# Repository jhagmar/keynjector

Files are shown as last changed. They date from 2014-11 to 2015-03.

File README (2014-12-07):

ABOUT THE PROJECT

There are several bad solutions to managing passwords securely, e.g.,

1) Having the same (easy to guess) password for every account
2) Keeping your passwords on a Post-It under your keyboard
3) Using a password manager on your computer

You might be surprised that item 3 made the list, but password managers keep all passwords in a file encrypted with a master password. When the user retrieves a password, all other passwords are decrypted and exposed in RAM, in an environment with dozens of other, potentially malicious, processes with internet access. Password managing software often use secure memory to increase security. However, a keylogger can be used to record the master password, and then we are back at the original problem.

The keynjector project tries to raise the bar by providing the password file decryption in a dedicated device, connected to the host with a USB cable. The password file, encrypted with OpenPGP symmetric encryption, is provided on a microSD card that the user inserts into the device. When the user requests a password, the device emulates a USB keyboard, and types the password on the host computer.

This solution offers a more secure solution compared to a traditional password manager:
1) There are no other processes running on the device that could potentially steal the information.
2) The USB keyboard interface is one-directional. There is no possibility for the host to inject code into the keynjector device.
3) The master password file can be easily removed and destroyed, e.g., by burning the microSD card, if needed.
4) The device can be used on any computer that recognizes a USB keyboard, without any loss of security.

The keynjector project consists of several sub-projects for the PCB layout, the firmware, the case for the device, etc. See below for a brief overview of the project directory structure.

GENERAL INFORMATION

Unless otherwise stated, all files in the keynjector project are Copyright Jonas Hagmar 2014, and licensed under GPL v2. A copy of the GPL v2 can be found in LICENSE.

Please refer to the AUTHORS file for contact information. 

DIRECTORY STRUCTURE

A brief overview of the directory structure of the project:

cad - CAD drawings

cad/case - OpenSCAD drawing of the case, suitable for 3D printing.

docs - documents

docs/datasheets - datasheets of components listed in the bill of materials (BOM)

hw - hardware designs

hw/bom - BOM for the hardware designs

hw/keynjector - KiCad project for the keynjector PCB

hw/zifbrkout - KiCad project for a breakout board which is helpful for testing the LCD connector on the keynjector board

misc - miscellaneous

misc/fonts - fonts used in the keynjector software

sw - software

sw/keynjector - Atmel Studio ASF project for the keynjector firmware

sw/keynjector_ui - Visual Studio 2010 project for desktop development of the keynjector UI, for faster iterations than trying out the code directly on the keynjector board

THIRD PARTY LICENSES

The project uses the following third party software:

Atmel ASF

/* Copyright (c) 2009-2014 Atmel Corporation. All rights reserved.
 *
 * \asf_license_start
 *
 * \page License
 *
 * Redistribution and use in source and binary forms, with or without
 * modification, are permitted provided that the following conditions are met:
 *
 * 1. Redistributions of source code must retain the above copyright notice,
 *    this list of conditions and the following disclaimer.
 *
 * 2. Redistributions in binary form must reproduce the above copyright notice,
 *    this list of conditions and the following disclaimer in the documentation
 *    and/or other materials provided with the distribution.
 *
 * 3. The name of Atmel may not be used to endorse or promote products derived
 *    from this software without specific prior written permission.
 *
 * 4. This software may only be redistributed and used in connection with an
 *    Atmel microcontroller product.
 *
 * THIS SOFTWARE IS PROVIDED BY ATMEL "AS IS" AND ANY EXPRESS OR IMPLIED
 * WARRANTIES, INCLUDING, BUT NOT LIMITED TO, THE IMPLIED WARRANTIES OF
 * MERCHANTABILITY, FITNESS FOR A PARTICULAR PURPOSE AND NON-INFRINGEMENT ARE
 * EXPRESSLY AND SPECIFICALLY DISCLAIMED. IN NO EVENT SHALL ATMEL BE LIABLE FOR
 * ANY DIRECT, INDIRECT, INCIDENTAL, SPECIAL, EXEMPLARY, OR CONSEQUENTIAL
 * DAMAGES (INCLUDING, BUT NOT LIMITED TO, PROCUREMENT OF SUBSTITUTE GOODS
 * OR SERVICES; LOSS OF USE, DATA, OR PROFITS; OR BUSINESS INTERRUPTION)
 * HOWEVER CAUSED AND ON ANY THEORY OF LIABILITY, WHETHER IN CONTRACT,
 * STRICT LIABILITY, OR TORT (INCLUDING NEGLIGENCE OR OTHERWISE) ARISING IN
 * ANY WAY OUT OF THE USE OF THIS SOFTWARE, EVEN IF ADVISED OF THE
 * POSSIBILITY OF SUCH DAMAGE.
 *
 * \asf_license_stop
 *
 */

CMSIS

* -------------------------------------------------------------------
* Copyright (C) 2011 ARM Limited. All rights reserved.  
* 
* Date:        11 October 2011  
* Revision:    V3.00 
*  
* Project:     Cortex Microcontroller Software Interface Standard (CMSIS)
* Title:       Release Note for CMSIS
*
* -------------------------------------------------------------------

NOTE - Open the index.html file to access CMSIS documentation

The Cortex Microcontroller Software Interface Standard (CMSIS) provides a single standard across all 
Cortex-Mx processor series vendors. It enables code re-use and code sharing across software projects 
and reduces time-to-market for new embedded applications.

CMSIS is released under the terms of the end user license agreement ("CMSIS END USER LICENCE AGREEMENT.pdf").
Any user of the software package is bound to the terms and conditions of the end user license agreement.

FatFS

 FatFs module is an open source software to implement FAT file system to
 small embedded systems. This is a free software and is opened for education,
 research and commercial developments under license policy of following trems.

  Copyright (C) 2011, ChaN, all right reserved.

 * The FatFs module is a free software and there is NO WARRANTY.
 * No restriction on use. You can use, modify and redistribute it for
   personal, non-profit or commercial product UNDER YOUR RESPONSIBILITY.
 * Redistributions of source code must retain the above copyright notice.

miniz

miniz is public domain and has the following license:

/*
  This is free and unencumbered software released into the public domain.

  Anyone is free to copy, modify, publish, use, compile, sell, or
  distribute this software, either in source code form or as a compiled
  binary, for any purpose, commercial or non-commercial, and by any
  means.

  In jurisdictions that recognize copyright laws, the author or authors
  of this software dedicate any and all copyright interest in the
  software to the public domain. We make this dedication for the benefit
  of the public at large and to the detriment of our heirs and
  successors. We intend this dedication to be an overt act of
  relinquishment in perpetuity of all present and future rights to this
  software under copyright law.

  THE SOFTWARE IS PROVIDED "AS IS", WITHOUT WARRANTY OF ANY KIND,
  EXPRESS OR IMPLIED, INCLUDING BUT NOT LIMITED TO THE WARRANTIES OF
  MERCHANTABILITY, FITNESS FOR A PARTICULAR PURPOSE AND NONINFRINGEMENT.
  IN NO EVENT SHALL THE AUTHORS BE LIABLE FOR ANY CLAIM, DAMAGES OR
  OTHER LIABILITY, WHETHER IN AN ACTION OF CONTRACT, TORT OR OTHERWISE,
  ARISING FROM, OUT OF OR IN CONNECTION WITH THE SOFTWARE OR THE USE OR
  OTHER DEALINGS IN THE SOFTWARE.

  For more information, please refer to <http://unlicense.org/>
*/

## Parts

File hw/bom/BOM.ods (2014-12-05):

# boards | 3
Unit | Part number | Link | Footprint | Qty/board | Fixed qty | Qty | Total qty
Processor | ATSAM4S8BA-ANR | http://www.digikey.se/product-detail/en/ATSAM4S8BA-ANR/ATSAM4S8BA-ANRCT-ND/4557105 | Yes (LQFP64) | 1 |  | 3 | 3
40 pin ZIF/FFC | FH12A-40S-0.5SH(55) | http://www.digikey.se/product-detail/en/FH12A-40S-0.5SH(55)/HFK140CT-ND/1110402 | Yes | 1 |  | 3 | 3
Voltage regulator | SPX3819M5-L/TR | http://www.digikey.se/product-detail/en/SPX3819M5-L%2FTR/1016-1871-1-ND/3586588 | Yes (SOT-23-5) | 1 |  | 3 | 3
Display | NHD-2.4-240320SF-CTXL#-FTN1 | http://www.digikey.se/product-detail/en/NHD-2.4-240320SF-CTXL%23-FTN1/NHD-2.4-240320SF-CTXL%23-FTN1-ND/4429440 | N/A | 1 |  | 3 | 3
10uF tantalum Capacitor, 16V 10% | TR3A106K016C1700 | http://www.digikey.se/product-detail/en/TR3A106K016C1700/718-1301-1-ND/1663023 | Yes (1206_10uF) | 1 |  | 3 | 3
Touch screen controller | ADS7843E | http://www.digikey.se/product-detail/en/ADS7843E/ADS7843E-ND/299533 | Yes (SSOP-16) | 1 |  | 3 | 3
Micro SD connector | 492250821 | http://www.digikey.se/product-detail/en/0492250821/WM3295CT-ND/2405740 | 492250821 | 1 |  | 3 | 3
Micro USB B connector | 10118192-0001LF | http://www.digikey.se/product-detail/en/10118192-0001LF/609-4613-1-ND/2785378 | Yes (10118192) | 1 |  | 3 | 3
100nF ceramic capacitor, 16V 10% | CL21B104KOANNNC | http://www.digikey.se/product-detail/en/CL21B104KOANNNC/1276-2448-1-ND/3890534 | Yes (0805) | 14 |  | 42 | 42
ESD protection diode | PRTR5V0U2X,215 | http://www.digikey.se/product-detail/en/PRTR5V0U2X,215/568-4140-1-ND/1589981 | Yes (SOT143B) | 1 |  | 3 | 3
15pF ceramic capacitor, 50V 5% | CL21C150JBANNNC | http://www.digikey.se/product-detail/en/CL21C150JBANNNC/1276-1163-1-ND/3889249 | Yes (0805) | 2 |  | 6 | 6
12 MHz crystal | 7A-12.000MAAJ-T | http://www.digikey.se/product-detail/en/7A-12.000MAAJ-T/887-1081-1-ND/2118958 | Yes 7A-12.000MAAJ-T) | 1 |  | 3 | 3
Atmel ICE debugger | ATATMEL-ICE | http://www.digikey.se/product-detail/en/ATATMEL-ICE/ATATMEL-ICE-ND/4753379 | N/A |  | 1 | 0 | 1
Solder 0.4mm leaded | 386844 | http://www.digikey.se/product-detail/en/386844/82-117-ND/2498915 | N/A |  | 1 | 0 | 1
Cortex debug header | M50-3600542 | http://www.digikey.se/product-detail/en/M50-3600542/952-1389-ND/2264370 | Yes (M50-3600542) | 1 |  | 3 | 3
Tactile switch | EVQ-P7L01P | http://www.digikey.se/product-detail/en/EVQ-P7L01P/P16769CT-ND/4429462 | Yes (EVQP7L01P) | 1 |  | 3 | 3
100K thick film resistor. 1/8W 1% | RMCF0805FT100K | http://www.digikey.se/product-detail/en/RMCF0805FT100K/RMCF0805FT100KCT-ND/1942491 | Yes (0805) | 0 |  | 0 | 0
36k thick film resistor, 1/8 W 1% | RMCF0805FT36K0 | http://www.digikey.se/product-detail/en/RMCF0805FT36K0/RMCF0805FT36K0CT-ND/2418379 | Yes (0805) | 1 |  | 3 | 3
56k thick film resistor, 1/8 W 1% | RC0805FR-0756KL | http://www.digikey.se/product-detail/en/RC0805FR-0756KL/311-56.0KCRCT-ND/730980 | Yes (0805) | 1 |  | 3 | 3
2.2uF tantalum capacitor, 10% 6Ohm | T491A225K016AT | http://www.digikey.se/product-detail/en/T491A225K016AT/399-3691-1-ND/819016 | Yes (1206_2.2uF) | 1 |  | 3 | 3
10uF ceramic capacitor, 16V 10% | CL21A106KOQNNNE | http://www.digikey.se/product-detail/en/CL21A106KOQNNNE/1276-1096-1-ND/3889182 | Yes (0805) | 4 |  | 12 | 12
39R thick film resistor, 1/8 W 1% | RC0805FR-0739RL | http://www.digikey.se/product-detail/en/RC0805FR-0739RL/311-39.0CRCT-ND/730845 | Yes (0805) | 3 |  | 9 | 9
10K thick film resistor. 1/8W 1% | RMCF0805FT10K0 | http://www.digikey.se/product-detail/en/RMCF0805FT10K0/RMCF0805FT10K0CT-ND/1942435 | Yes (0805) | 2 |  | 6 | 6
zifbrkout
FFC cable | 687640050002 | http://www.digikey.se/product-detail/en/687640050002/732-3571-ND/2811293 |  | 1
LED | LY R976-PS-36 | http://www.digikey.se/product-detail/en/LY%20R976-PS-36/475-2560-1-ND/1802687 |  | 40
330R resistor | RMCF0805FT330R | http://www.digikey.se/product-detail/en/RMCF0805FT330R/RMCF0805FT330RCT-ND/1942351 |  | 40
Vertical ZIF connector | 501951-4000 | http://www.digikey.se/product-detail/en/501951-4000/WM2075CT-ND/1952421 |  | 1
Accessories
10x loupe | 26034 | http://www.digikey.se/product-detail/en/26034/243-1021-ND/600975 |  |  | 1 | 0 | 1
loupe headgear | 26225 | http://www.digikey.se/product-detail/en/26225/243-1124-ND/2756906 |  |  | 1 | 0 | 1
Solder wick | OS-B-5AS | http://www.digikey.se/product-detail/en/OS-B-5AS/EB1102-ND/350557 |  |  | 1 | 0 | 1
Flux paste | SMD291 | http://www.digikey.se/product-detail/en/SMD291/SMD291-ND/355201 |  |  | 1 | 0 | 1
1/32" solder tip | LTH | http://www.digikey.se/product-detail/en/LTH/LTH-ND/267992 |  |  | 1 | 0 | 1
0.4 mm solder tip | LT1SLX | http://www.digikey.se/product-detail/en/LT1SLX/LT1SLX-ND/588691 |  |  | 1 | 0 | 1
Flux pen/liquid flux |  | http://www.electrokit.com/flussmedel-penna-10ml.49540 |  |  | 1 | 0 | 1
 |  | http://www.electrokit.com/flussmedel-penna-noclean-10ml.50507 |  |  |  | 0 | 0
Solder practice kit | SMDPST100 | http://www.digikey.se/product-search/en?FV=fff40026,fff80267,fffc013b&chp=0 |  |  | 1 | 0 | 1
Removal kit | SMD1 | http://www.digikey.se/product-detail/en/SMD1/SMD1-ND/304148 |  |  | 1 | 0 | 1
Vacuum tool | HVPB6 | http://www.digikey.se/product-detail/en/HVPB6/HVPB6-ND/1164270 |  |  | 1 | 0 | 1
Tweezers | 18072EZ | http://www.digikey.se/product-detail/en/18072EZ/243-1055-ND/1657714 |  |  | 1 | 0 | 1
Dry tip cleaner |  | http://www.electrokit.com/lodspetsrengorare-metallull.50289 |  |  | 1 | 0 | 1
Tip tinner | SMDTCLF | http://www.digikey.se/product-detail/en/SMDTCLF/SMDTCLF-ND/2177048 |  |  | 1 | 0 | 1

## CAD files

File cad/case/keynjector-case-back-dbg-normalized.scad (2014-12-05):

/*
* Copyright 2014 Jonas Hagmar
*
* This file is part of keynjector.
*
* keynjector is free software: you can redistribute it and/or modify
* it under the terms of the GNU General Public License as published by
* the Free Software Foundation, either version 2 of the License, or
* (at your option) any later version.
*
* keynjector is distributed in the hope that it will be useful,
* but WITHOUT ANY WARRANTY; without even the implied warranty of
* MERCHANTABILITY or FITNESS FOR A PARTICULAR PURPOSE.  See the
* GNU General Public License for more details.
*
* You should have received a copy of the GNU General Public License
* along with keynjector.  If not, see <http://www.gnu.org/licenses/>.
*/

use <keynjector-case.scad>;

/***** Renders *****/

$fn=100;

case_back_dbg_normalized();

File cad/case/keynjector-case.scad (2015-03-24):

/*
* Copyright 2014 Jonas Hagmar
*
* This file is part of keynjector.
*
* keynjector is free software: you can redistribute it and/or modify
* it under the terms of the GNU General Public License as published by
* the Free Software Foundation, either version 2 of the License, or
* (at your option) any later version.
*
* keynjector is distributed in the hope that it will be useful,
* but WITHOUT ANY WARRANTY; without even the implied warranty of
* MERCHANTABILITY or FITNESS FOR A PARTICULAR PURPOSE.  See the
* GNU General Public License for more details.
*
* You should have received a copy of the GNU General Public License
* along with keynjector.  If not, see <http://www.gnu.org/licenses/>.
*/

/***** Parameters *****/

tol = 0.1; // tolerance
eps = 0.01;
wall_thickness = 1; // thickness of case wall
front_thickness = 0.5; // thickness of front wall
pcb_width = 42.94 + tol;
pcb_drawing_height = 35.96;
pcb_height = 36.2 + tol;
pcb_depth = 1.76 + tol;
component_depth = 2.7 + tol; // largest component is USB connector
screen_width = 42.72 + tol;
screen_height = 60.26 + tol;
screen_back_film_thickness = 0.1;
screen_depth = 3.6 + screen_back_film_thickness + tol;
screen_top = 2.9; // distance from top to viewport
holder_height = 10; // height of screen holder
holder_width = 8;
usb_a = 4.75;
usb_b = 7.86;
usb_c = 2.8;
usb_zoffset = -0.1;
btn_width = 2;
btn_height = 10;
btn_y_offset = -7.24;
btn_base_height = 12;
btn_base_depth = 0.95;
btn_ratio = 0.95; // ration of button size to hole
btn_protrude = 0.5;
sd_y_offset = -18.3;
sd_height = 12;
sd_depth = 2;
nut_depth = 1.6; // max depth of DIN 934 M2 nut
nut_diameter = 4; // diameter of DIN 934 M2 nut
nut_clearance = 0.2;
screw_head_diameter = 3.8; // DIN 965 M2
screw_body_diameter = 2; // DIN 965 M2
screw_depth = 5;
dbg_y_offset = -26; // offset for debug header window
dbg_holder_dent_size = 2;
dbg_x_offset = -8; 
pcb_real_height_offset = (pcb_height - pcb_drawing_height)/2;
usb_coord = [[usb_a/2,0], [usb_b/2, (usb_b - usb_a)/2],
	[usb_b/2, usb_c], [-usb_b/2, usb_c],
	[-usb_b/2, (usb_b - usb_a)/2], [-usb_a/2, 0]];
case_width = pcb_width + 2*wall_thickness;
case_height = screen_height + 2*wall_thickness;
case_depth = pcb_depth + component_depth + screen_depth + wall_thickness
	+ front_thickness;
fillet_radius = 1;
screen_x2 = [screen_width/2, case_height/2 - wall_thickness,
	case_depth/2 - front_thickness];
screen_x1 = screen_x2 - [screen_width, screen_height, screen_depth];
pcb_x2 = [pcb_width/2, case_height/2 - wall_thickness,
	-case_depth/2 + pcb_depth + wall_thickness];
pcb_x1 = pcb_x2 - [pcb_width, pcb_height, pcb_depth];
comp_x2 = pcb_x2 + [0,0,component_depth]; // component layer
comp_x1 = pcb_x1 + [0,0,pcb_depth];
cable_x2 = [case_width/2 - wall_thickness, pcb_x1[1] + eps,
	case_depth/2 - front_thickness];
cable_x1 = [-case_width/2 + wall_thickness, 
	-case_height/2 + wall_thickness, -case_depth/2 + wall_thickness]; 
viewport_fillet_radius = front_thickness;
viewport_width = 36.72;
viewport_height = 48.96;
viewport_x2 = [viewport_width/2 + viewport_fillet_radius,
	case_height/2 - wall_thickness - screen_top + viewport_fillet_radius, 
	case_depth/2 + wall_thickness];
viewport_x1 = [viewport_x2[0] - viewport_width - 2*viewport_fillet_radius,
	viewport_x2[1] - viewport_height - 2*viewport_fillet_radius,
	viewport_x2[2] - case_depth];
holder1_x1 = [-case_width/2 + wall_thickness,
	pcb_x1[1] - holder_height, -case_depth/2 + wall_thickness];
holder1_x2 = [holder1_x1[0] + holder_width, holder1_x1[1] + holder_height,
	case_depth/2 - front_thickness - screen_depth];
holder2_x1 = holder1_x1 
	+ [case_width - 2*wall_thickness - holder_width,0,0];
holder2_x2 = holder1_x2 
	+ [case_width - 2*wall_thickness - holder_width,0,0];
dbg_x2 = [case_width/2 - wall_thickness + eps,
	case_height/2 - wall_thickness + dbg_y_offset,
	case_depth/2 - front_thickness - eps];
dbg_x1 = [dbg_x2[0] + dbg_x_offset,
	pcb_x1[1] - dbg_holder_dent_size, -case_depth/2 - eps];
sup_size = 1; // size of display support
sup1_x1 = [pcb_x1[0], pcb_x2[1] - sup_size, pcb_x1[2]-eps];
sup1_x2 = [sup1_x1[0]+sup_size, sup1_x1[1]+sup_size, 
	sup1_x1[2]+pcb_depth+component_depth+eps];
sup2_x1 = sup1_x1 + [pcb_width - sup_size, 0, 0];
sup2_x2 = sup1_x2 + [pcb_width - sup_size, 0, 0];


/***** Renders *****/

//$fn=20;

case_back();
//case_back_normalized();

//case_back_dbg();
//case_back_dbg_normalized();

holder();
//holder_normalized();

case_front();
//case_front_normalized();

btn();
//btn_normalized();

/***** Modules *****/

module translated_sphere(r, x) {
	translate(x)
		sphere(r);
}

// construct a rounded cube by taking the hull of
// spheres in the corners
module rounded_cube(w, h, d, r) {
	hull() {
		translated_sphere(r, [w/2 - r, h/2 - r, 
			d/2 - r]);
		translated_sphere(r, [-w/2 + r, h/2 - r, 
			d/2 - r]);
		translated_sphere(r, [w/2 - r, -h/2 + r, 
			d/2 - r]);
		translated_sphere(r, [-w/2 + r, -h/2 + r, 
			d/2 - r]);
		translated_sphere(r, [w/2 - r, h/2 - r, 
			-d/2 + r]);
		translated_sphere(r, [-w/2 + r, h/2 - r, 
			-d/2 + r]);
		translated_sphere(r, [w/2 - r, -h/2 + r, 
			-d/2 + r]);
		translated_sphere(r, [-w/2 + r, -h/2 + r, 
			-d/2 + r]);	
	}
}

// convenience module to draw cube at specified coordinates
module box(x1, x2) {
	translate(x1)
			cube(x2 - x1);
}

// the solid body of the case
module case_body() {
	rounded_cube(case_width, case_height, case_depth, fillet_radius);
}

// viewport cut-out
module viewport_cut_out() {
	box(viewport_x1, viewport_x2);
}

// viewport fillet
module viewport_fillet() {
	union() {
		hull() {
			translated_sphere(viewport_fillet_radius,
				[viewport_x1[0], viewport_x1[1], 
					case_depth/2-viewport_fillet_radius]);
			translated_sphere(viewport_fillet_radius,
				[viewport_x1[0], viewport_x2[1], 
					case_depth/2-viewport_fillet_radius]);
		}
		hull() {
			translated_sphere(viewport_fillet_radius,
				[viewport_x1[0], viewport_x1[1], 
					case_depth/2-viewport_fillet_radius]);
			translated_sphere(viewport_fillet_radius,
				[viewport_x2[0], viewport_x1[1], 
					case_depth/2-viewport_fillet_radius]);
		}
		hull() {
			translated_sphere(viewport_fillet_radius,
				[viewport_x2[0], viewport_x2[1], 
					case_depth/2-viewport_fillet_radius]);
			translated_sphere(viewport_fillet_radius,
				[viewport_x1[0], viewport_x2[1], 
					case_depth/2-viewport_fillet_radius]);
		}
		hull() {
			translated_sphere(viewport_fillet_radius,
				[viewport_x2[0], viewport_x2[1], 
					case_depth/2-viewport_fillet_radius]);
			translated_sphere(viewport_fillet_radius,
				[viewport_x2[0], viewport_x1[1], 
					case_depth/2-viewport_fillet_radius]);
		}
	}
}

// lcd
module screen() {
	box(screen_x1, screen_x2);
}

// pcb with components
module pcb() {
	box(pcb_x1, pcb_x2 + [0,0,eps]);
}

module components() {
	box(comp_x1, comp_x2 + [0,0,eps]);
}

// empty space for cable
module cable_hole() {
	box(cable_x1, cable_x2);
}

// hole for micro usb B plug
module usb_hole() {
	translate([0, case_height/2, 
		-case_depth/2 + wall_thickness + pcb_depth + usb_zoffset])
	rotate(90, [1,0,0])
	linear_extrude(wall_thickness + eps)
	polygon(usb_coord);
}

// hole for user button
module btn_hole() {
	translate([case_width/2 + eps,
		case_height/2 - wall_thickness + btn_y_offset 
		- pcb_real_height_offset,
		- case_depth/2 + wall_thickness + pcb_depth + btn_width/2])
	rotate(-90, [0,0,1])
	rotate(90, [1,0,0])
	linear_extrude(wall_thickness + 2*eps) {
		hull() {
			translate([-btn_height/2 + btn_width/2,0,0])
				circle(btn_width/2);
			translate([btn_height/2 - btn_width/2,0,0])
				circle(btn_width/2);
		}
	}
}

// user button translated to have center at 0
module btn_normalized() {
	union() {
		linear_extrude(btn_base_depth)
		translate([-btn_base_height/2, -btn_width/2,0])
		square([btn_base_height, btn_width]);
		color([1,0,0])
		translate([0,0,btn_base_depth - eps])	
		linear_extrude(wall_thickness + btn_protrude + eps) {
			hull() {
				translate([btn_ratio * (-btn_height/2 + btn_width/2),0,0])
					circle(btn_ratio * btn_width/2);
				translate([btn_ratio *  (btn_height/2 - btn_width/2),0,0])
					circle(btn_ratio * btn_width/2);
			}
		}
	}
}

// user button
module btn() {
	translate([case_width/2,
		case_height/2 - wall_thickness + btn_y_offset 
		- pcb_real_height_offset,
		- case_depth/2 + wall_thickness + pcb_depth + btn_width/2])
	rotate(90, [0,0,1])
	rotate(90, [1,0,0])
	translate([0,0,-(btn_base_depth + wall_thickness)])
	btn_normalized();
}

// micro sd card slot
module sd_hole() {
	translate([-case_width/2 - eps,
		case_height/2 - wall_thickness + sd_y_offset 
		- pcb_real_height_offset,
		- case_depth/2 + wall_thickness + pcb_depth])
	rotate(90, [0,0,1])
	rotate(90, [1,0,0])
	linear_extrude(wall_thickness + 2*eps)
	translate([-sd_height/2, 0, 0])
	square([sd_height, sd_depth]);

}

// screen holders
module holder() {

	difference() {
		box(holder1_x1, holder1_x2);
		screws();
		nuts();
	}
	
	difference() {
		box(holder2_x1, holder2_x2);
		screws();
		nuts();
	}
	
}
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

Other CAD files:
cad/case/keynjector-case-back-normalized.scad
cad/case/keynjector-case-front-normalized.scad
cad/case/keynjector-holder-and-btn-normalized.scad

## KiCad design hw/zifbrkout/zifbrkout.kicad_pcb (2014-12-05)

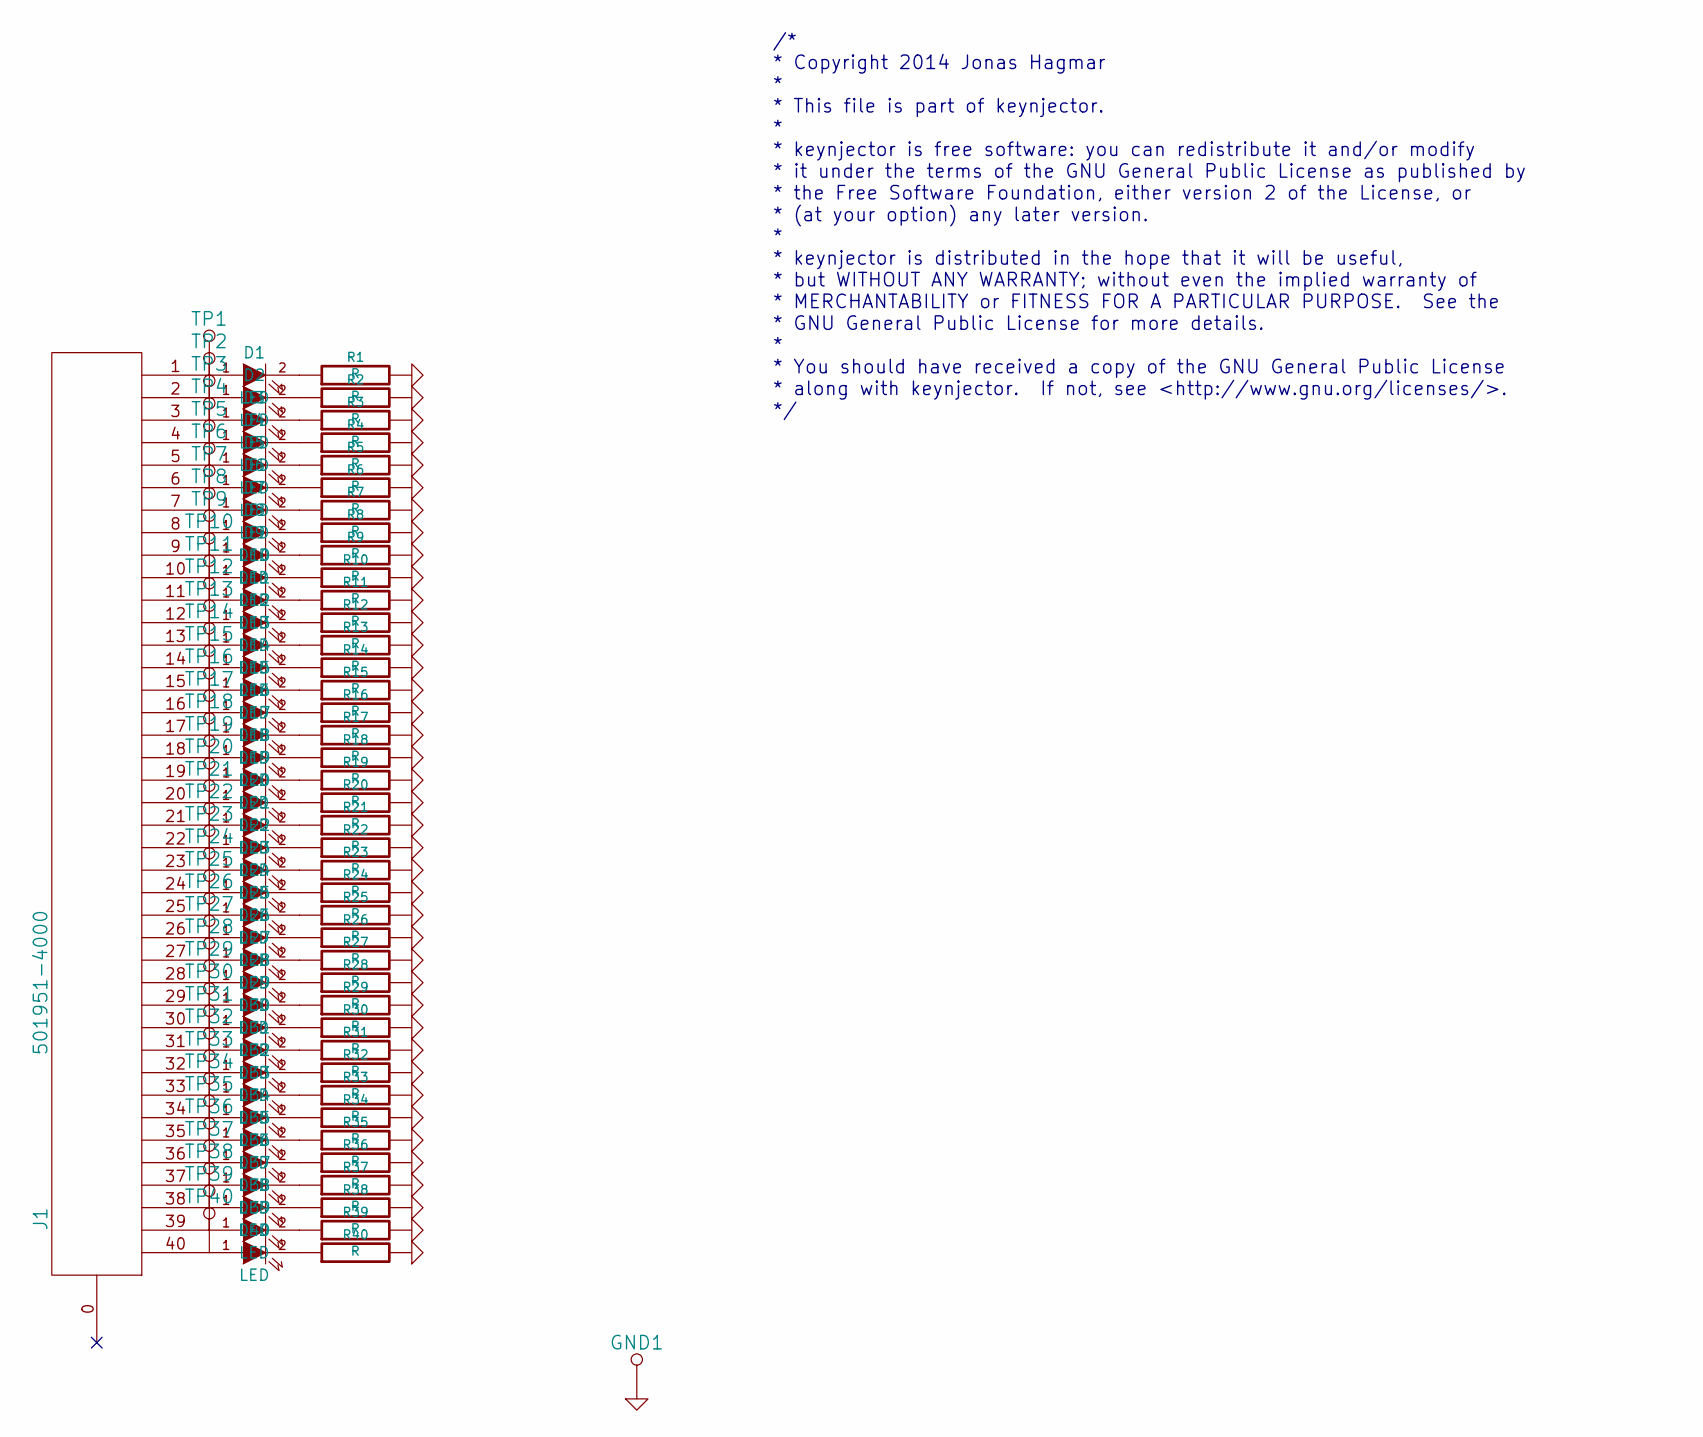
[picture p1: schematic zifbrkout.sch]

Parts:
D1, D2, D3, D4, D5, D6, D7, D8, D9, D10, D11, D12, D13, D14, D15, D16, D17, D18, D19, D20, D21, D22, D23, D24, D25, D26, D27, D28, D29, D30, D31, D32, D33, D34, D35, D36, D37, D38, D39, D40: LED
GND1: EXTGND
J1: 501951-4000
R1, R2, R3, R4, R5, R6, R7, R8, R9, R10, R11, R12, R13, R14, R15, R16, R17, R18, R19, R20, R21, R22, R23, R24, R25, R26, R27, R28, R29, R30, R31, R32, R33, R34, R35, R36, R37, R38, R39, R40: R
TP1, TP2, TP3, TP4, TP5, TP6, TP7, TP8, TP9, TP10, TP11, TP12, TP13, TP14, TP15, TP16, TP17, TP18, TP19, TP20, TP21, TP22, TP23, TP24, TP25, TP26, TP27, TP28, TP29, TP30, TP31, TP32, TP33, TP34, TP35, TP36, TP37, TP38, TP39, TP40: TP

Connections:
GND: GND1.1, R1.2, R2.2, R3.2, R4.2, R5.2, R6.2, R7.2, R8.2, R9.2, R10.2, R11.2, R12.2, R13.2, R14.2, R15.2, R16.2, R17.2, R18.2, R19.2, R20.2, R21.2, R22.2, R23.2, R24.2, R25.2, R26.2, R27.2, R28.2, R29.2, R30.2, R31.2, R32.2, R33.2, R34.2, R35.2, R36.2, R37.2, R38.2, R39.2, R40.2
unnamed: D26.2 (K), R26.1
unnamed: D31.2 (K), R31.1
unnamed: D30.2 (K), R30.1
unnamed: D29.2 (K), R29.1
unnamed: D28.2 (K), R28.1
unnamed: D27.2 (K), R27.1
unnamed: D25.2 (K), R25.1
unnamed: D24.2 (K), R24.1
unnamed: D23.2 (K), R23.1
unnamed: D22.2 (K), R22.1
unnamed: D40.2 (K), R40.1
unnamed: D39.2 (K), R39.1
unnamed: D38.2 (K), R38.1
unnamed: D37.2 (K), R37.1
unnamed: D36.2 (K), R36.1
unnamed: D35.2 (K), R35.1
unnamed: D34.2 (K), R34.1
unnamed: D33.2 (K), R33.1
unnamed: D32.2 (K), R32.1
unnamed: D11.1 (A), J1.11, TP11.1
unnamed: D24.1 (A), J1.24, TP24.1
unnamed: D14.1 (A), J1.14, TP14.1
unnamed: D33.1 (A), J1.33, TP33.1
unnamed: D23.1 (A), J1.23, TP23.1
unnamed: D13.1 (A), J1.13, TP13.1
unnamed: D32.1 (A), J1.32, TP32.1
unnamed: D22.1 (A), J1.22, TP22.1
unnamed: D12.1 (A), J1.12, TP12.1
unnamed: D31.1 (A), J1.31, TP31.1
unnamed: D21.1 (A), J1.21, TP21.1
unnamed: D34.1 (A), J1.34, TP34.1
unnamed: D40.1 (A), J1.40, TP40.1
unnamed: D30.1 (A), J1.30, TP30.1
unnamed: D20.1 (A), J1.20, TP20.1
unnamed: D10.1 (A), J1.10, TP10.1
unnamed: D9.1 (A), J1.9, TP9.1
unnamed: D8.1 (A), J1.8, TP8.1
unnamed: D7.1 (A), J1.7, TP7.1
unnamed: D6.1 (A), J1.6, TP6.1
unnamed: D5.1 (A), J1.5, TP5.1
unnamed: D18.1 (A), J1.18, TP18.1
unnamed: D39.1 (A), J1.39, TP39.1
unnamed: D29.1 (A), J1.29, TP29.1
unnamed: D19.1 (A), J1.19, TP19.1
unnamed: D38.1 (A), J1.38, TP38.1
unnamed: D28.1 (A), J1.28, TP28.1
unnamed: D4.1 (A), J1.4, TP4.1
unnamed: D37.1 (A), J1.37, TP37.1
unnamed: D27.1 (A), J1.27, TP27.1
unnamed: D17.1 (A), J1.17, TP17.1
unnamed: D36.1 (A), J1.36, TP36.1
unnamed: D26.1 (A), J1.26, TP26.1
unnamed: D16.1 (A), J1.16, TP16.1
unnamed: D35.1 (A), J1.35, TP35.1
unnamed: D25.1 (A), J1.25, TP25.1
unnamed: D15.1 (A), J1.15, TP15.1
unnamed: D3.1 (A), J1.3, TP3.1
unnamed: D2.1 (A), J1.2, TP2.1
unnamed: D1.1 (A), J1.1, TP1.1
unnamed: D21.2 (K), R21.1
unnamed: D8.2 (K), R8.1
unnamed: D7.2 (K), R7.1
unnamed: D6.2 (K), R6.1
unnamed: D5.2 (K), R5.1
unnamed: D4.2 (K), R4.1
unnamed: D9.2 (K), R9.1
unnamed: D3.2 (K), R3.1
unnamed: D2.2 (K), R2.1
unnamed: D14.2 (K), R14.1
unnamed: D18.2 (K), R18.1
unnamed: D17.2 (K), R17.1
unnamed: D16.2 (K), R16.1
unnamed: D15.2 (K), R15.1
unnamed: D13.2 (K), R13.1
unnamed: D12.2 (K), R12.1
unnamed: D11.2 (K), R11.1
unnamed: D10.2 (K), R10.1
unnamed: D1.2 (K), R1.1
unnamed: D19.2 (K), R19.1
unnamed: D20.2 (K), R20.1

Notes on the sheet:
/* * Copyright 2014 Jonas Hagmar * * This file is part of keynjector. * * keynjector is free software: you can redistribute it and/or modify * it under the terms of the GNU General Public License as published by * the Free Software Foundation, either version 2 of the License, or * (at your option) 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

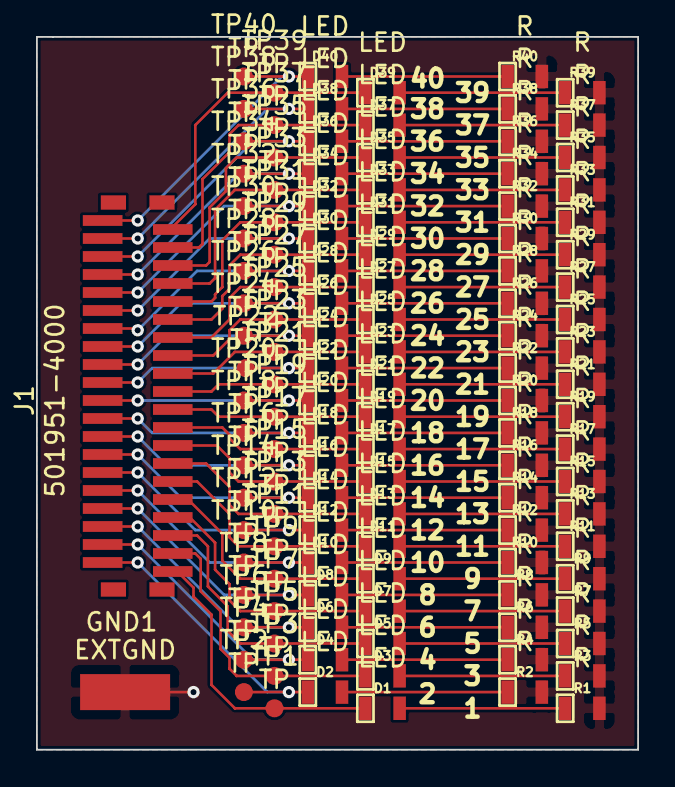
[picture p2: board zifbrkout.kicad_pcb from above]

Board: 2 copper layers, 33.4 x 39.6 mm, 122 parts (0 on the bottom side), 81 nets.

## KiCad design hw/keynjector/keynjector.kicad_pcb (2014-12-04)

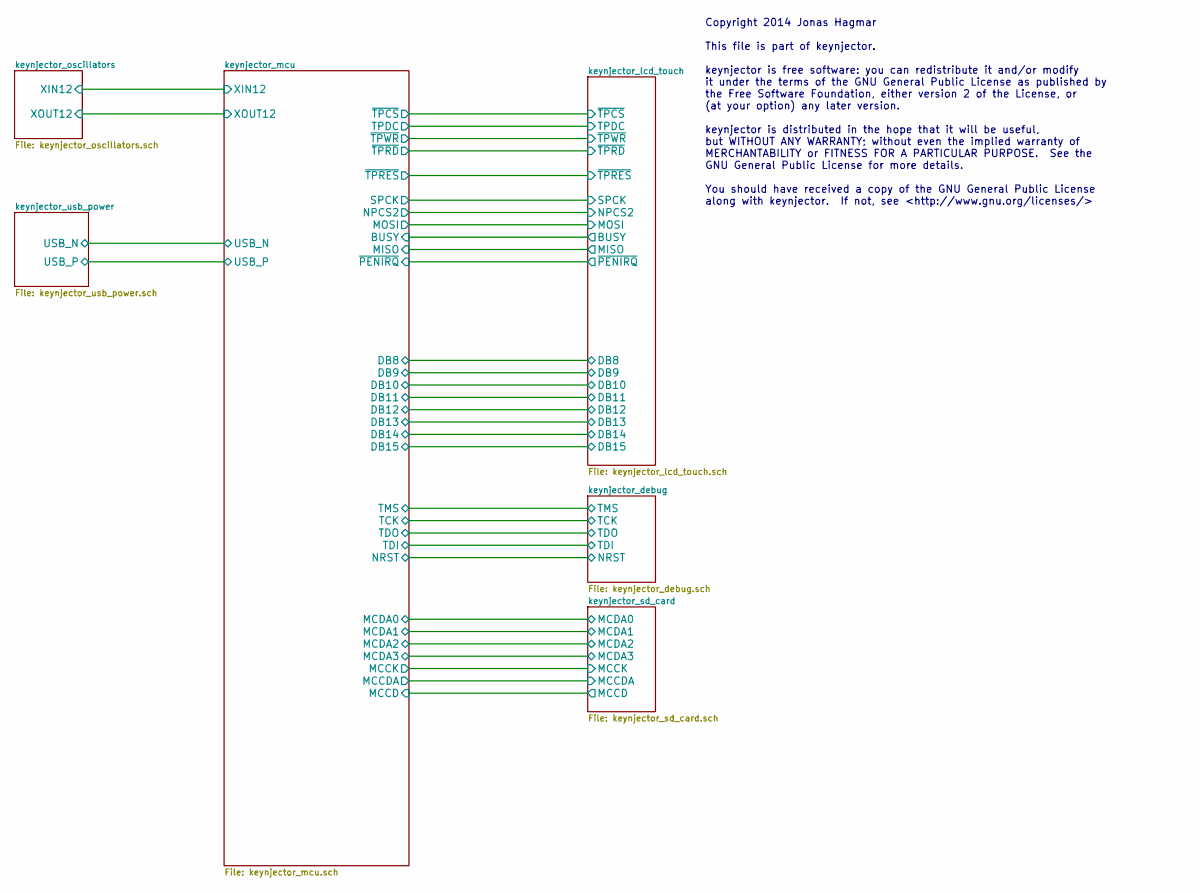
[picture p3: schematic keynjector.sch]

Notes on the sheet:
Copyright 2014 Jonas Hagmar This file is part of keynjector. keynjector is free software: you can redistribute it and/or modify it under the terms of the GNU General Public License as published by the Free Software Foundation, either version 2 of the License, or (at your option) any later version. 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

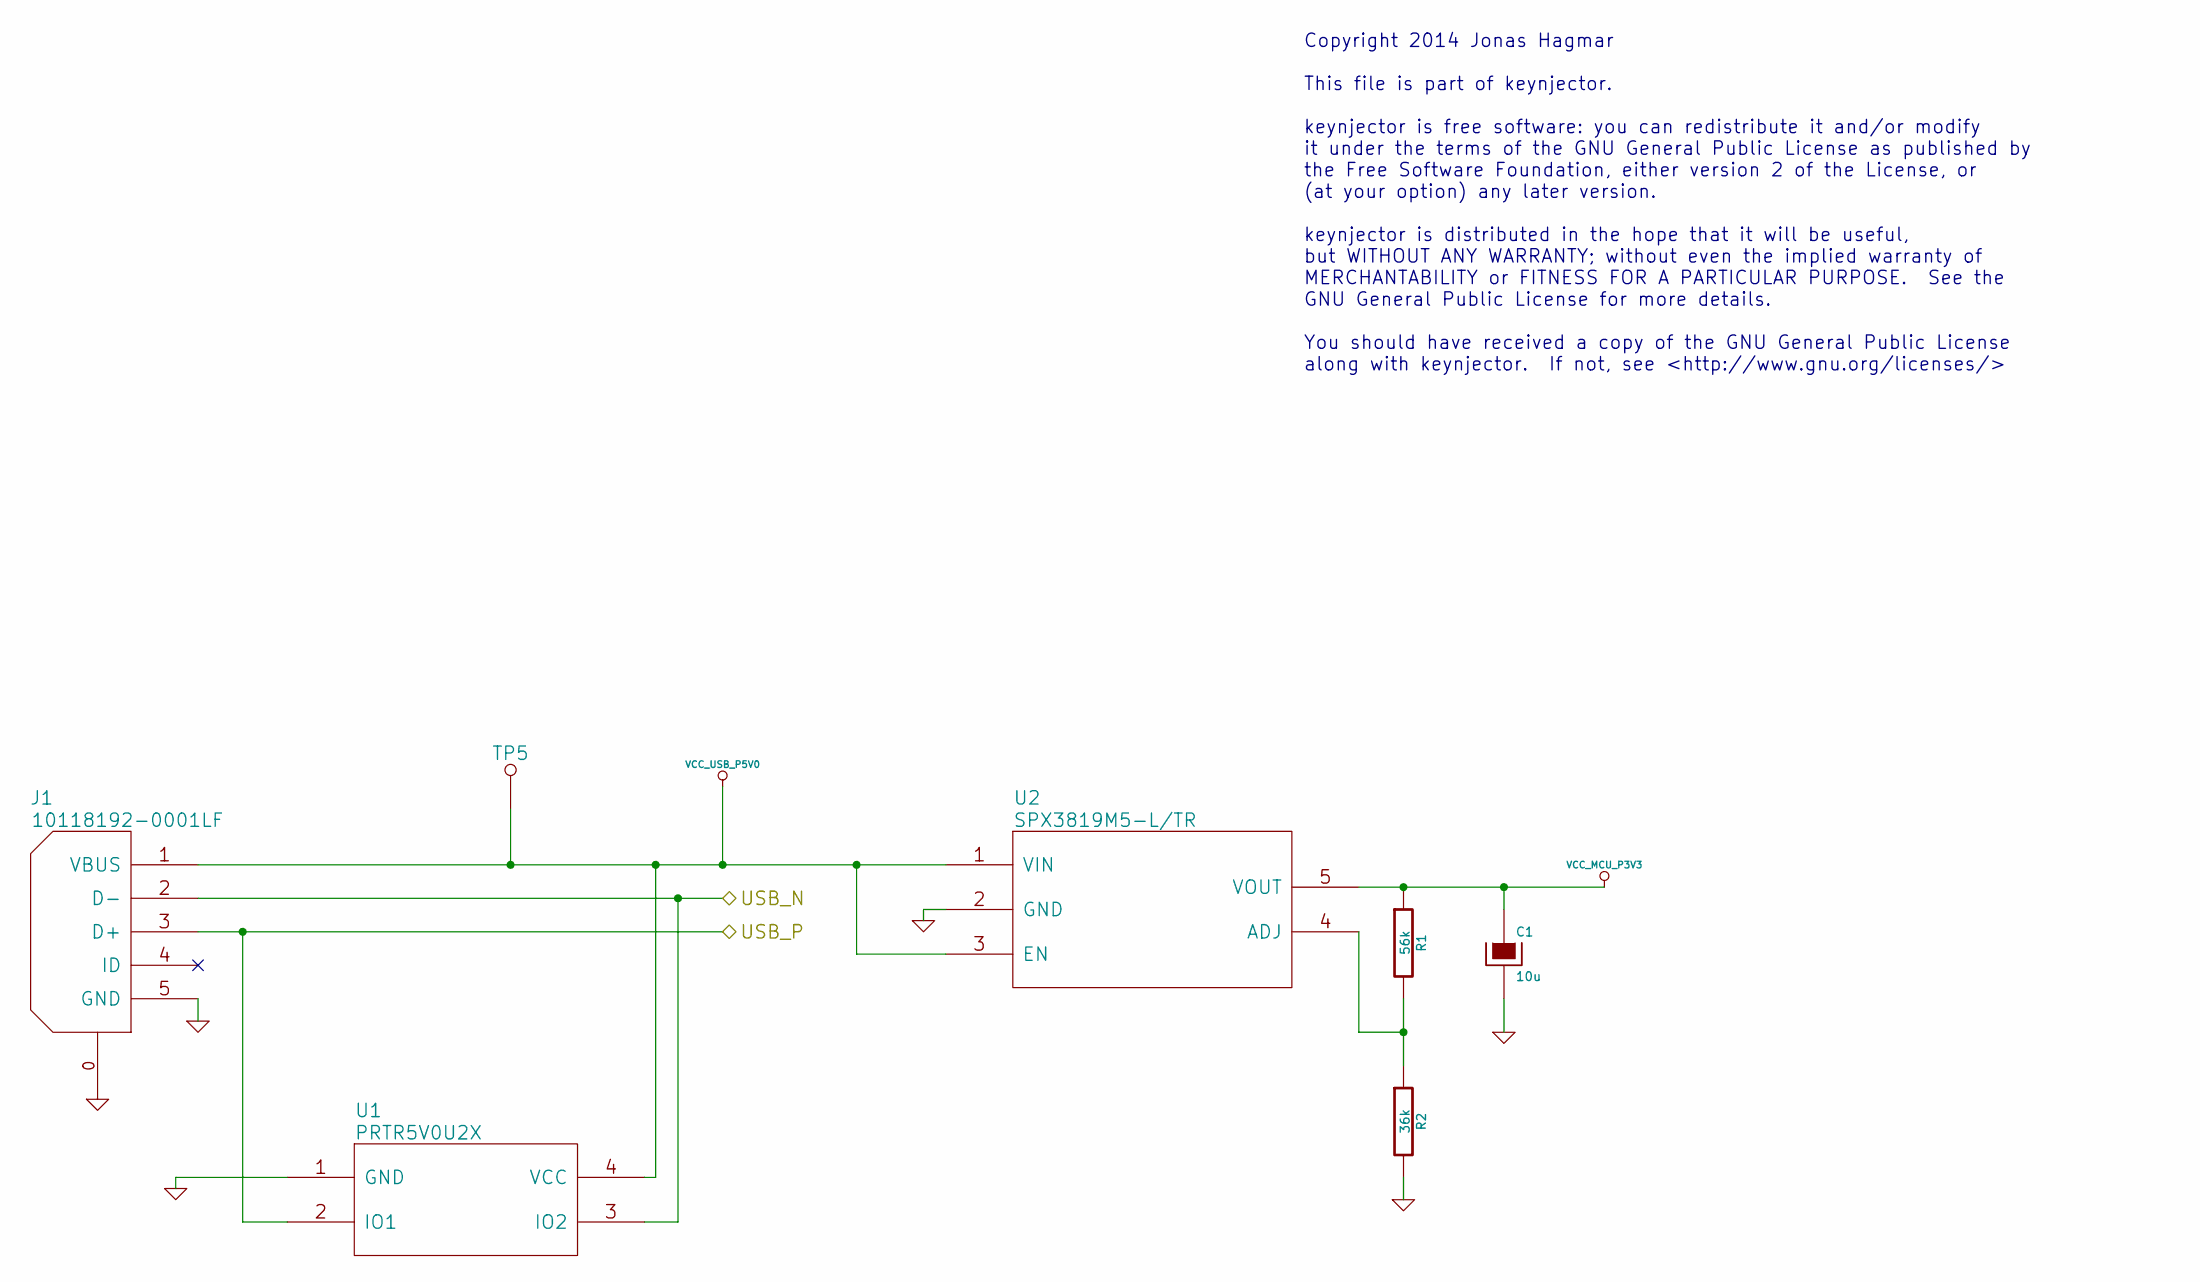
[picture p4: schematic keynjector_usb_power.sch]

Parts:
C1: 10u
J1: 10118192-0001LF
R1: 56k
R2: 36k
TP5: TP
U1: PRTR5V0U2X
U2: SPX3819M5-L/TR

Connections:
/keynjector_mcu/USB_N: J1.2 (D-), U1.3 (IO2); also elsewhere on the board
/keynjector_mcu/USB_P: J1.3 (D+), U1.2 (IO1); also elsewhere on the board
GND: C1.2, J1.0, J1.5 (GND), R2.2, U1.1 (GND), U2.2 (GND); also elsewhere on the board
unnamed: R1.2, R2.1, U2.4 (ADJ)
VCC_MCU_P3V3: C1.1, R1.1, U2.5 (VOUT); also elsewhere on the board
VCC_USB_P5V0: J1.1 (VBUS), TP5.1, U1.4 (VCC), U2.1 (VIN), U2.3 (EN)

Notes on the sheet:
Copyright 2014 Jonas Hagmar This file is part of keynjector. keynjector is free software: you can redistribute it and/or modify it under the terms of the GNU General Public License as published by the Free Software Foundation, either version 2 of the License, or (at your option) any later version. 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

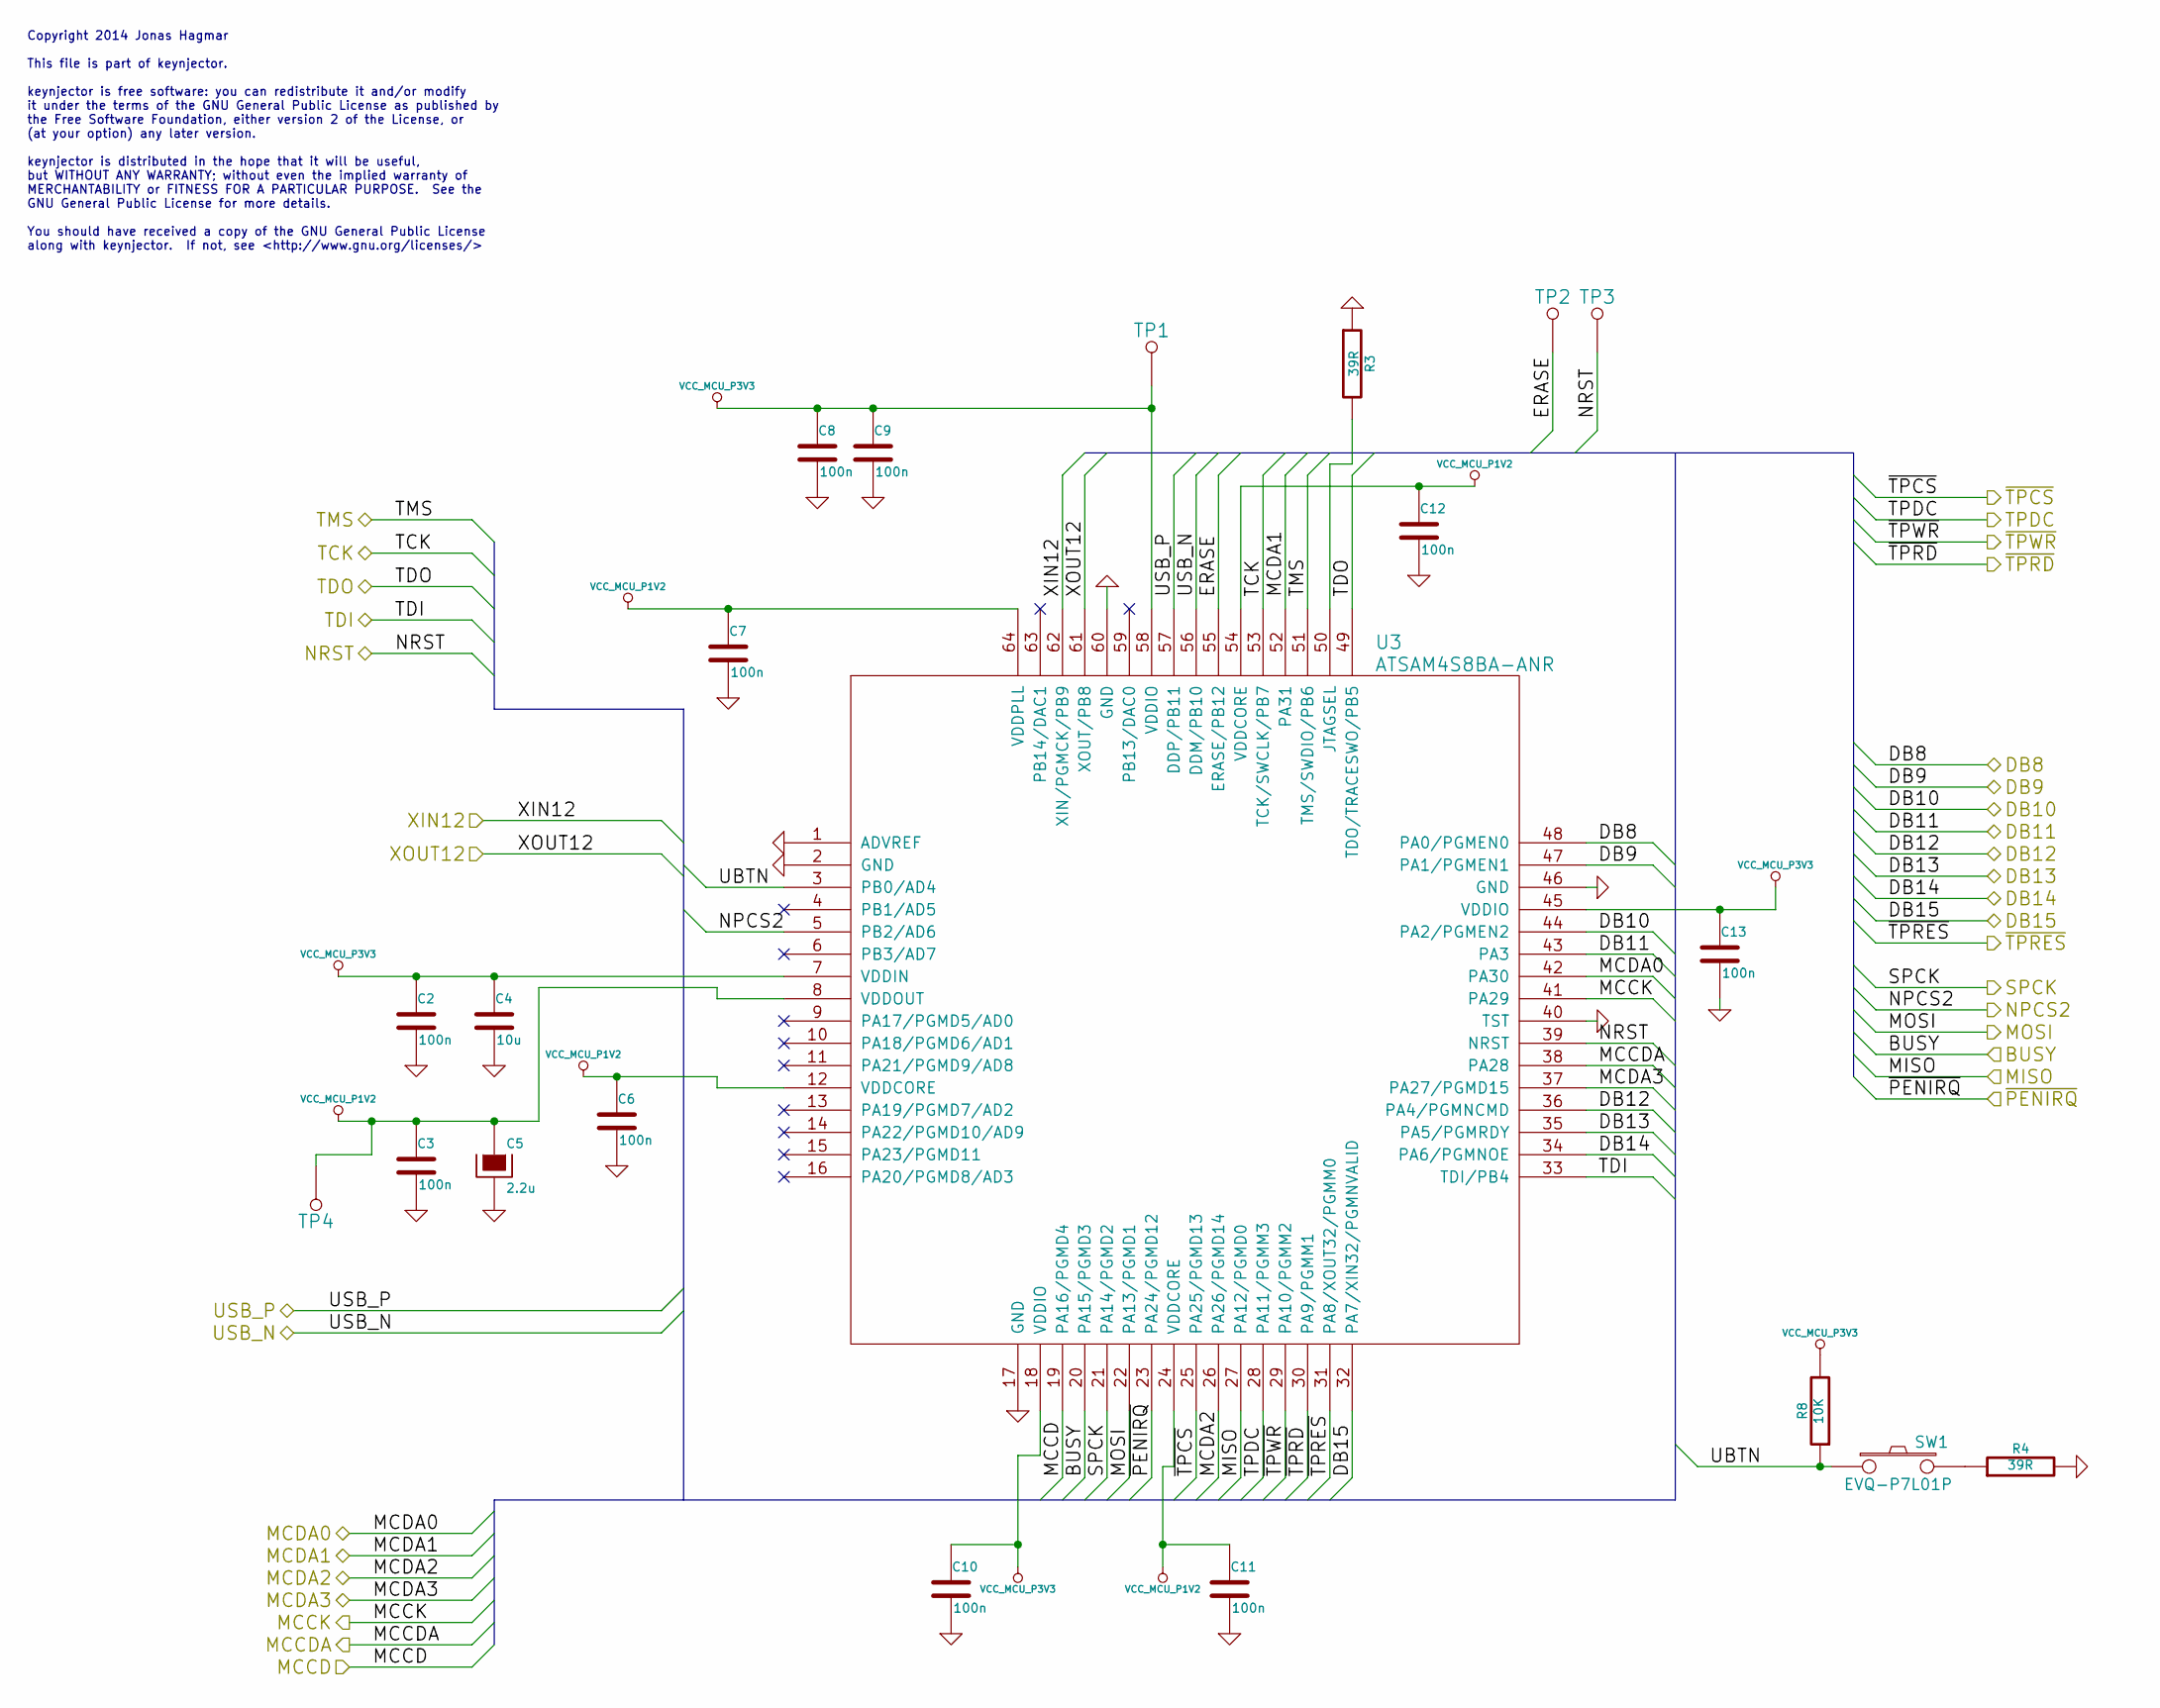
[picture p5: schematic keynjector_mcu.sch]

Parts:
C2, C3, C6, C7, C8, C9, C10, C11, C12, C13: 100n
C4: 10u
C5: 2.2u
R3, R4: 39R
R8: 10K
SW1: EVQ-P7L01P
TP1, TP2, TP3, TP4: TP
U3: ATSAM4S8BA-ANR

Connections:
/keynjector_debug/NRST: TP3.1, U3.39 (NRST); also elsewhere on the board
/keynjector_debug/TCK: U3.53 (TCK/SWCLK/PB7); also elsewhere on the board
/keynjector_debug/TDI: U3.33 (TDI/PB4); also elsewhere on the board
/keynjector_debug/TDO: U3.49 (TDO/TRACESWO/PB5); also elsewhere on the board
/keynjector_debug/TMS: U3.51 (TMS/SWDIO/PB6); also elsewhere on the board
/keynjector_lcd_touch/BUSY: U3.20 (PA15/PGMD3); also elsewhere on the board
/keynjector_lcd_touch/DB8: U3.48 (PA0/PGMEN0); also elsewhere on the board
/keynjector_lcd_touch/DB9: U3.47 (PA1/PGMEN1); also elsewhere on the board
/keynjector_lcd_touch/DB10: U3.44 (PA2/PGMEN2); also elsewhere on the board
/keynjector_lcd_touch/DB11: U3.43 (PA3); also elsewhere on the board
/keynjector_lcd_touch/DB12: U3.36 (PA4/PGMNCMD); also elsewhere on the board
/keynjector_lcd_touch/DB13: U3.35 (PA5/PGMRDY); also elsewhere on the board
/keynjector_lcd_touch/DB14: U3.34 (PA6/PGMNOE); also elsewhere on the board
/keynjector_lcd_touch/DB15: U3.32 (PA7/XIN32/PGMNVALID); also elsewhere on the board
/keynjector_lcd_touch/MISO: U3.27 (PA12/PGMD0); also elsewhere on the board
/keynjector_lcd_touch/MOSI: U3.22 (PA13/PGMD1); also elsewhere on the board
/keynjector_lcd_touch/NPCS2: U3.5 (PB2/AD6); also elsewhere on the board
/keynjector_lcd_touch/SPCK: U3.21 (PA14/PGMD2); also elsewhere on the board
/keynjector_lcd_touch/TPDC: U3.28 (PA11/PGMM3); also elsewhere on the board
/keynjector_lcd_touch/~PENIRQ: U3.23 (PA24/PGMD12); also elsewhere on the board
/keynjector_lcd_touch/~TPCS: U3.25 (PA25/PGMD13); also elsewhere on the board
/keynjector_lcd_touch/~TPRD: U3.30 (PA9/PGMM1); also elsewhere on the board
/keynjector_lcd_touch/~TPRES: U3.31 (PA8/XOUT32/PGMM0); also elsewhere on the board
/keynjector_lcd_touch/~TPWR: U3.29 (PA10/PGMM2); also elsewhere on the board
/keynjector_mcu/ERASE: TP2.1, U3.55 (ERASE/PB12)
/keynjector_mcu/MCCD: U3.19 (PA16/PGMD4); also elsewhere on the board
/keynjector_mcu/MCCDA: U3.38 (PA28); also elsewhere on the board
/keynjector_mcu/MCCK: U3.41 (PA29); also elsewhere on the board
/keynjector_mcu/MCDA0: U3.42 (PA30); also elsewhere on the board
/keynjector_mcu/MCDA1: U3.52 (PA31); also elsewhere on the board
/keynjector_mcu/MCDA2: U3.26 (PA26/PGMD14); also elsewhere on the board
/keynjector_mcu/MCDA3: U3.37 (PA27/PGMD15); also elsewhere on the board
/keynjector_mcu/UBTN: R8.1, SW1.1, U3.3 (PB0/AD4)
/keynjector_mcu/USB_N: U3.56 (DDM/PB10); also elsewhere on the board
/keynjector_mcu/USB_P: U3.57 (DDP/PB11); also elsewhere on the board
/keynjector_mcu/XIN12: U3.62 (XIN/PGMCK/PB9); also elsewhere on the board
/keynjector_mcu/XOUT12: U3.61 (XOUT/PB8); also elsewhere on the board
GND: C2.2, C3.2, C4.2, C5.2, C6.2, C7.2, C8.2, C9.2, C10.2, C11.2, C12.2, C13.2, R3.1, R4.2, U3.1 (ADVREF), U3.2 (GND), U3.17 (GND), U3.40 (TST), U3.46 (GND), U3.60 (GND); also elsewhere on the board
unnamed: R3.2, U3.50 (JTAGSEL)
unnamed: R4.1, SW1.2
VCC_MCU_P1V2: C3.1, C5.1, C6.1, C7.1, C11.1, C12.1, TP4.1, U3.8 (VDDOUT), U3.12 (VDDCORE), U3.24 (VDDCORE), U3.54 (VDDCORE), U3.64 (VDDPLL)
VCC_MCU_P3V3: C2.1, C4.1, C8.1, C9.1, C10.1, C13.1, R8.2, TP1.1, U3.7 (VDDIN), U3.18 (VDDIO), U3.45 (VDDIO), U3.58 (VDDIO); also elsewhere on the board

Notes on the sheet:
Copyright 2014 Jonas Hagmar This file is part of keynjector. keynjector is free software: you can redistribute it and/or modify it under the terms of the GNU General Public License as published by the Free Software Foundation, either version 2 of the License, or (at your option) any later version. 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

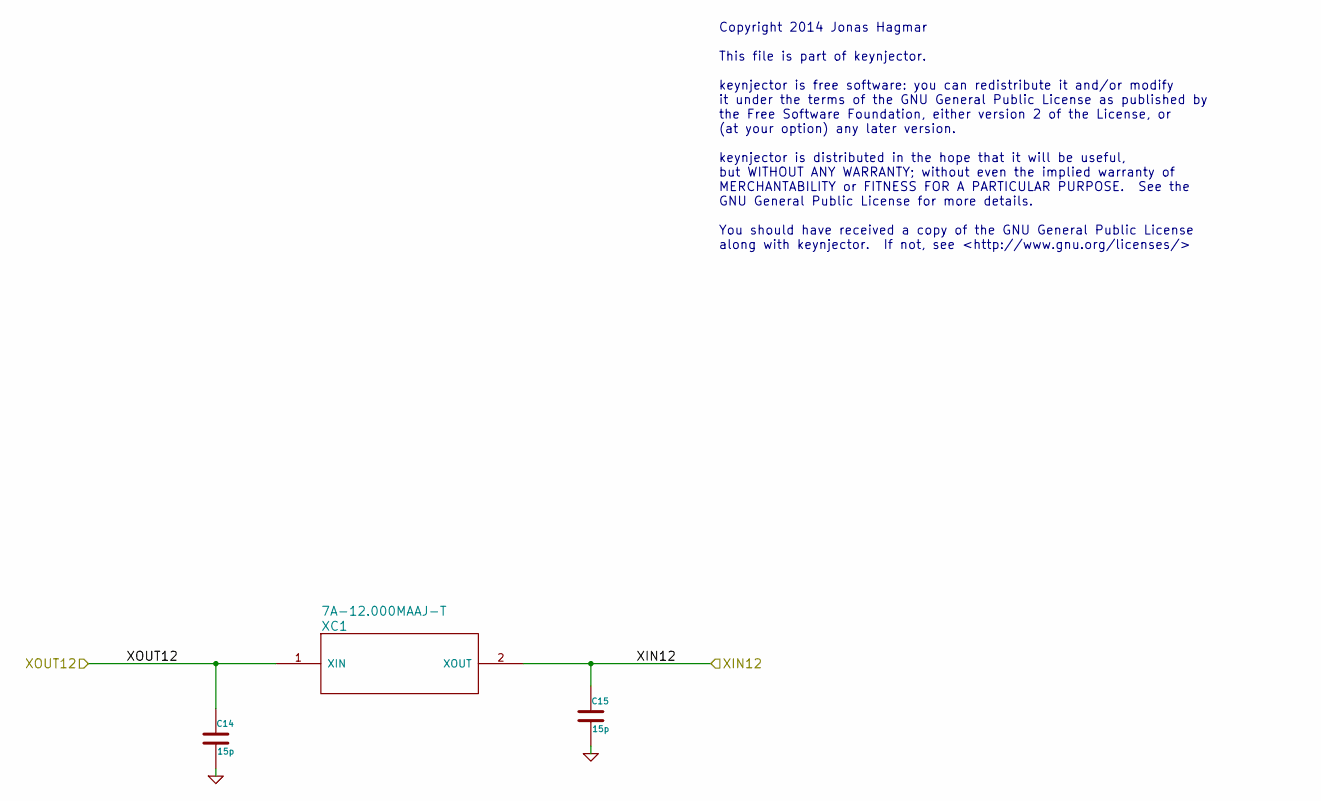
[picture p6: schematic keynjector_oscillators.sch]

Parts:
C14, C15: 15p
XC1: 7A-12.000MAAJ-T

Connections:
/keynjector_mcu/XIN12: C15.1, XC1.2 (XOUT); also elsewhere on the board
/keynjector_mcu/XOUT12: C14.1, XC1.1 (XIN); also elsewhere on the board
GND: C14.2, C15.2; also elsewhere on the board

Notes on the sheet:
Copyright 2014 Jonas Hagmar This file is part of keynjector. keynjector is free software: you can redistribute it and/or modify it under the terms of the GNU General Public License as published by the Free Software Foundation, either version 2 of the License, or (at your option) any later version. 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

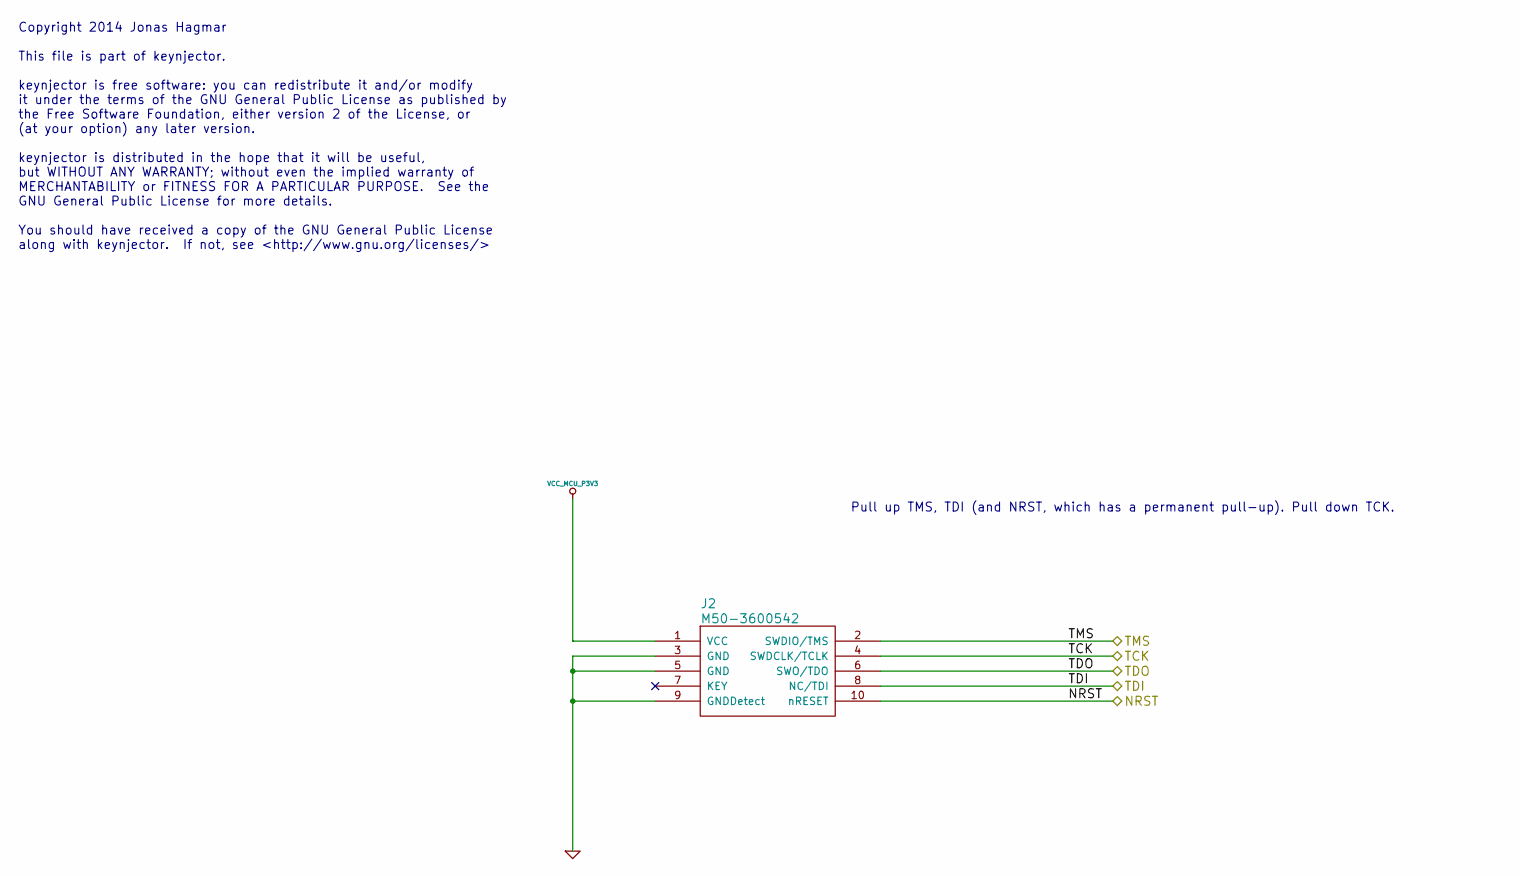
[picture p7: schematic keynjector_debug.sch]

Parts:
J2: M50-3600542

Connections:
/keynjector_debug/NRST: J2.10 (nRESET); also elsewhere on the board
/keynjector_debug/TCK: J2.4 (SWDCLK/TCLK); also elsewhere on the board
/keynjector_debug/TDI: J2.8 (NC/TDI); also elsewhere on the board
/keynjector_debug/TDO: J2.6 (SWO/TDO); also elsewhere on the board
/keynjector_debug/TMS: J2.2 (SWDIO/TMS); also elsewhere on the board
GND: J2.3 (GND), J2.5 (GND), J2.9 (GNDDetect); also elsewhere on the board
VCC_MCU_P3V3: J2.1 (VCC); also elsewhere on the board

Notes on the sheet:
Pull up TMS, TDI (and NRST, which has a permanent pull-up). Pull down TCK.
Copyright 2014 Jonas Hagmar This file is part of keynjector. keynjector is free software: you can redistribute it and/or modify it under the terms of the GNU General Public License as published by the Free Software Foundation, either version 2 of the License, or (at your option) any later version. 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

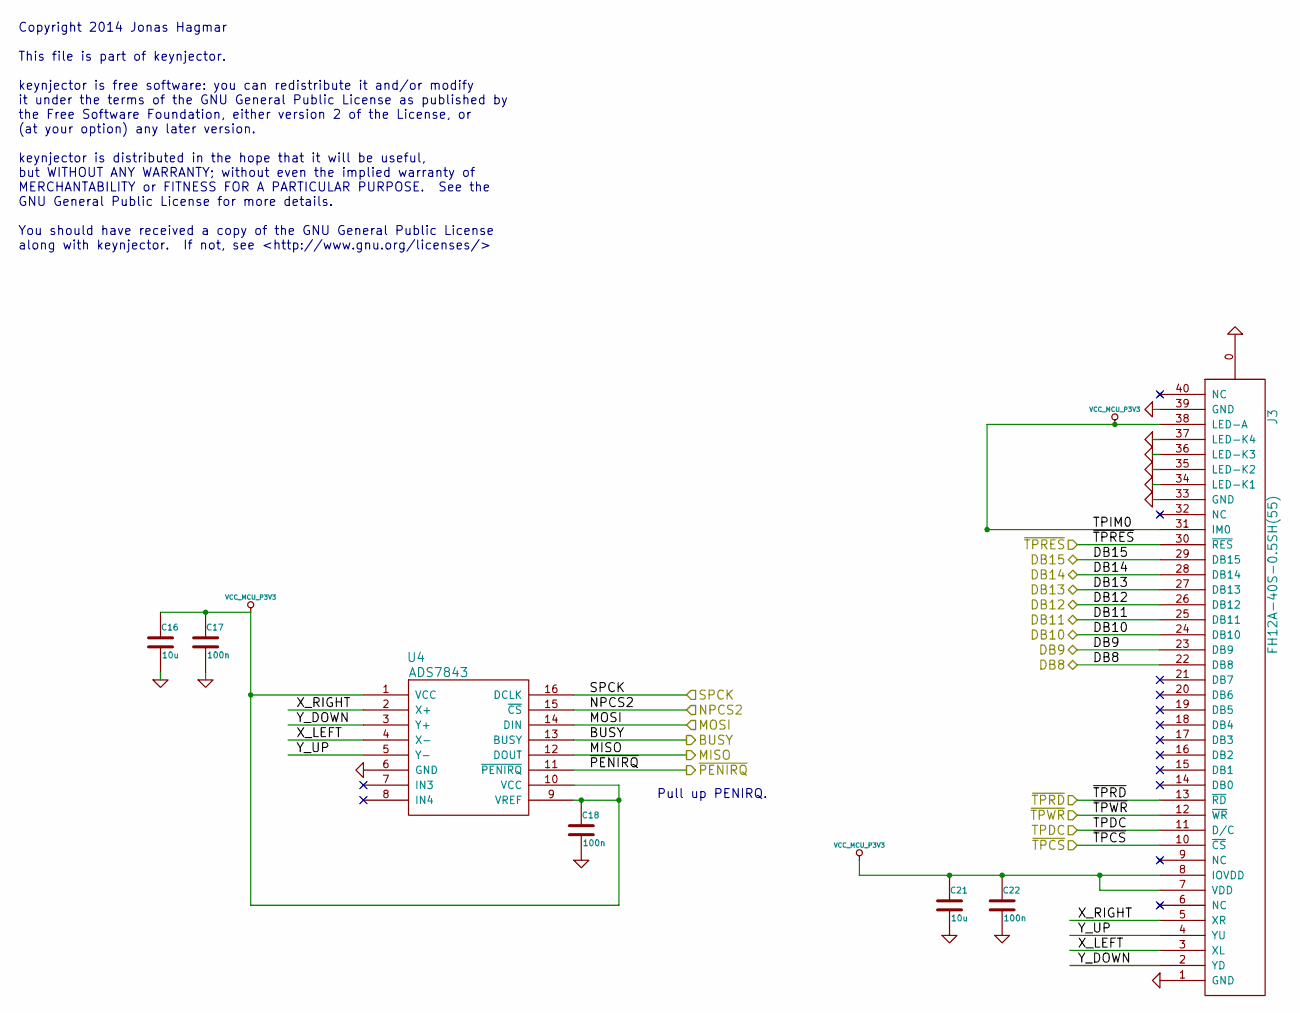
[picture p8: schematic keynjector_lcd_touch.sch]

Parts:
C16, C21: 10u
C17, C18, C22: 100n
J3: FH12A-40S-0.5SH(55)
U4: ADS7843

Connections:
/keynjector_lcd_touch/BUSY: U4.13 (BUSY); also elsewhere on the board
/keynjector_lcd_touch/DB8: J3.22 (DB8); also elsewhere on the board
/keynjector_lcd_touch/DB9: J3.23 (DB9); also elsewhere on the board
/keynjector_lcd_touch/DB10: J3.24 (DB10); also elsewhere on the board
/keynjector_lcd_touch/DB11: J3.25 (DB11); also elsewhere on the board
/keynjector_lcd_touch/DB12: J3.26 (DB12); also elsewhere on the board
/keynjector_lcd_touch/DB13: J3.27 (DB13); also elsewhere on the board
/keynjector_lcd_touch/DB14: J3.28 (DB14); also elsewhere on the board
/keynjector_lcd_touch/DB15: J3.29 (DB15); also elsewhere on the board
/keynjector_lcd_touch/MISO: U4.12 (DOUT); also elsewhere on the board
/keynjector_lcd_touch/MOSI: U4.14 (DIN); also elsewhere on the board
/keynjector_lcd_touch/NPCS2: U4.15 (~CS); also elsewhere on the board
/keynjector_lcd_touch/SPCK: U4.16 (DCLK); also elsewhere on the board
/keynjector_lcd_touch/TPDC: J3.11 (D/C); also elsewhere on the board
/keynjector_lcd_touch/X_LEFT: J3.3 (XL), U4.4 (X-)
/keynjector_lcd_touch/X_RIGHT: J3.5 (XR), U4.2 (X+)
/keynjector_lcd_touch/Y_DOWN: J3.2 (YD), U4.3 (Y+)
/keynjector_lcd_touch/Y_UP: J3.4 (YU), U4.5 (Y-)
/keynjector_lcd_touch/~PENIRQ: U4.11 (~PENIRQ); also elsewhere on the board
/keynjector_lcd_touch/~TPCS: J3.10 (~CS); also elsewhere on the board
/keynjector_lcd_touch/~TPRD: J3.13 (~RD); also elsewhere on the board
/keynjector_lcd_touch/~TPRES: J3.30 (~RES); also elsewhere on the board
/keynjector_lcd_touch/~TPWR: J3.12 (~WR); also elsewhere on the board
GND: C16.2, C17.2, C18.2, C21.2, C22.2, J3.0, J3.1 (GND), J3.33 (GND), J3.34 (LED-K1), J3.35 (LED-K2), J3.36 (LED-K3), J3.37 (LED-K4), J3.39 (GND), U4.6 (GND); also elsewhere on the board
VCC_MCU_P3V3: C16.1, C17.1, C18.1, C21.1, C22.1, J3.7 (VDD), J3.8 (IOVDD), J3.31 (IM0), J3.38 (LED-A), U4.1 (VCC), U4.9 (VREF), U4.10 (VCC); also elsewhere on the board

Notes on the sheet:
Pull up PENIRQ.
Copyright 2014 Jonas Hagmar This file is part of keynjector. keynjector is free software: you can redistribute it and/or modify it under the terms of the GNU General Public License as published by the Free Software Foundation, either version 2 of the License, or (at your option) any later version. 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

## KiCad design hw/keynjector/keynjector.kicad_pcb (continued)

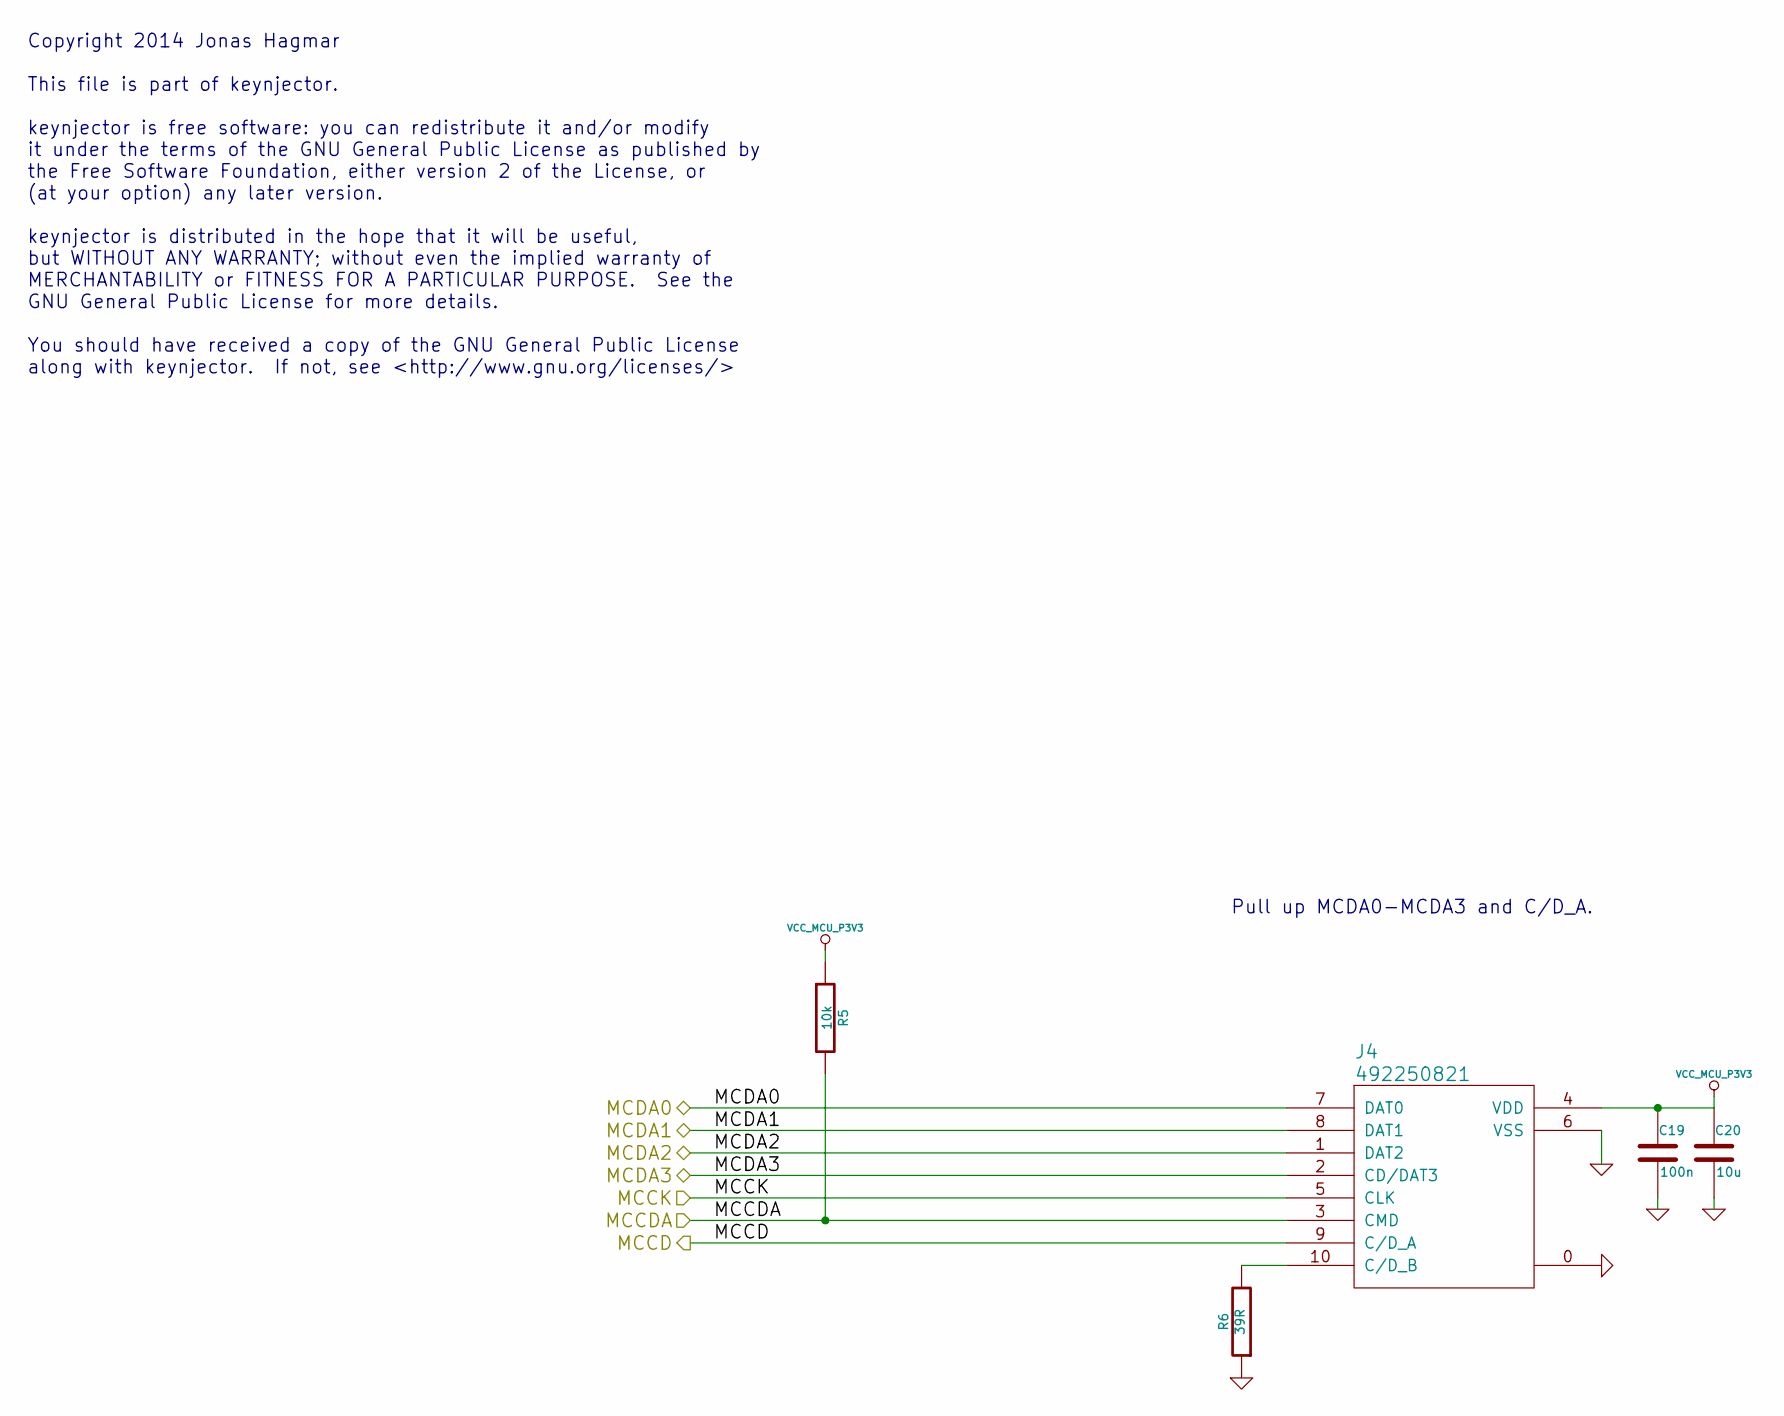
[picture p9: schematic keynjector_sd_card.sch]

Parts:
C19: 100n
C20: 10u
J4: 492250821
R5: 10k
R6: 39R

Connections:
/keynjector_mcu/MCCD: J4.9 (C/D_A); also elsewhere on the board
/keynjector_mcu/MCCDA: J4.3 (CMD), R5.2; also elsewhere on the board
/keynjector_mcu/MCCK: J4.5 (CLK); also elsewhere on the board
/keynjector_mcu/MCDA0: J4.7 (DAT0); also elsewhere on the board
/keynjector_mcu/MCDA1: J4.8 (DAT1); also elsewhere on the board
/keynjector_mcu/MCDA2: J4.1 (DAT2); also elsewhere on the board
/keynjector_mcu/MCDA3: J4.2 (CD/DAT3); also elsewhere on the board
GND: C19.2, C20.2, J4.0, J4.6 (VSS), R6.1; also elsewhere on the board
unnamed: J4.10 (C/D_B), R6.2
VCC_MCU_P3V3: C19.1, C20.1, J4.4 (VDD), R5.1; also elsewhere on the board

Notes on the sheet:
Pull up MCDA0-MCDA3 and C/D_A.
Copyright 2014 Jonas Hagmar This file is part of keynjector. keynjector is free software: you can redistribute it and/or modify it under the terms of the GNU General Public License as published by the Free Software Foundation, either version 2 of the License, or (at your option) any later version. 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

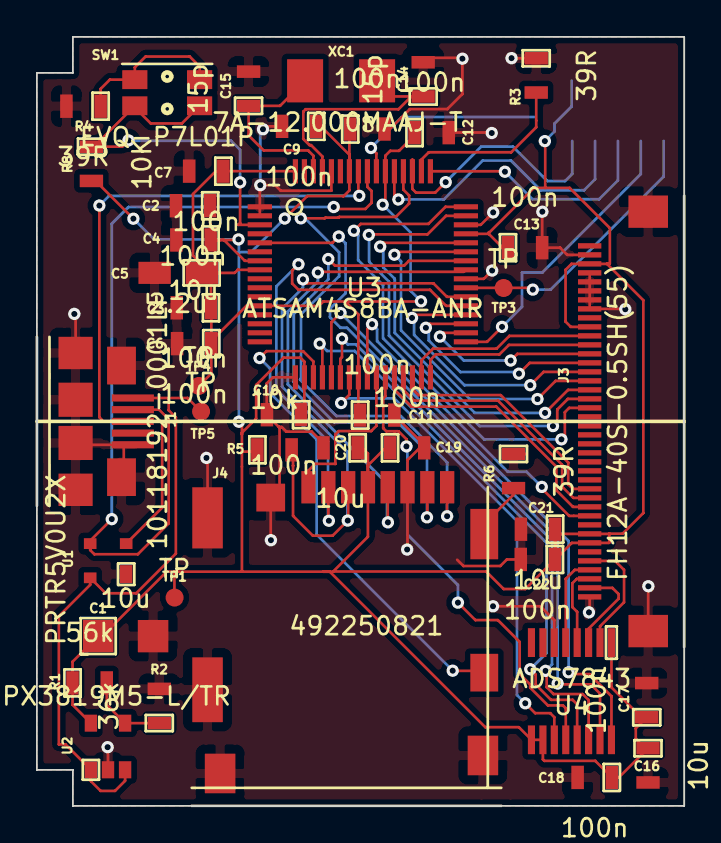
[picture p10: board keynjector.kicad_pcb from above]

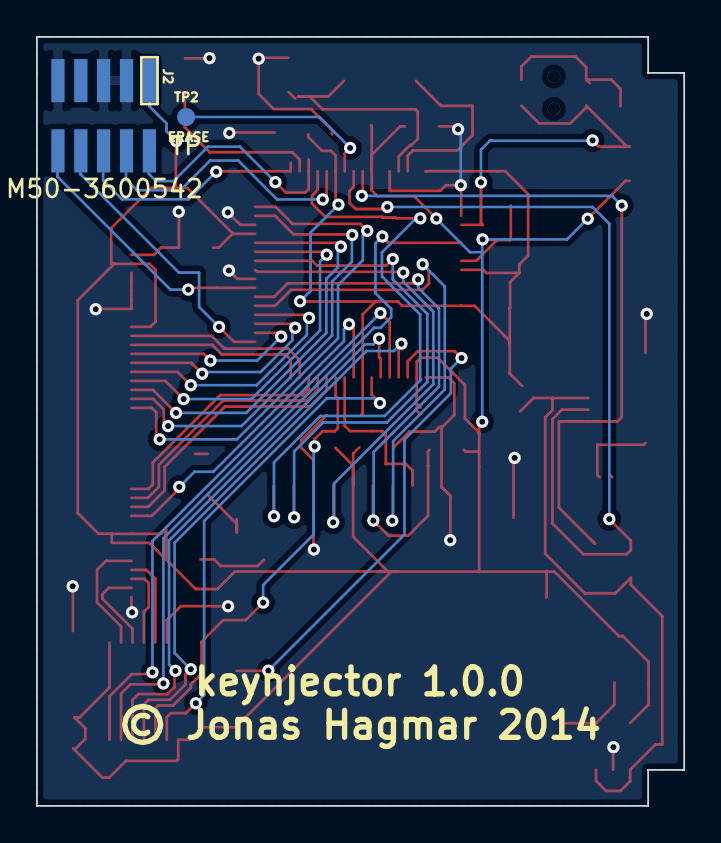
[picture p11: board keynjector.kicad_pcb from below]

Board: 2 copper layers, 36.0 x 42.7 mm, 44 parts (2 on the bottom side), 49 nets.

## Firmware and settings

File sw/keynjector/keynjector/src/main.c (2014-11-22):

/*
* Copyright 2014 Jonas Hagmar
*
* This file is part of keynjector.
*
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
* You should have received a copy of the GNU General Public License
* along with keynjector.  If not, see <http://www.gnu.org/licenses/>.
*/
#include <stdlib.h>
#include <string.h>
#include <asf.h>
#include "lcd.h"
#include "ui.h"
#include "qsort.h"
#include "opgp.h"
#include "ff_stream.h"
#include "send_keys.h"
#include "sha1.h"

static volatile uint32_t g_ul_tick_count = 0;

// handler for system tick (every 1ms)
void SysTick_Handler(void)
{
	g_ul_tick_count++;

	// update touch panel status every 10ms
	// and lcd animation every 50ms
	if ((g_ul_tick_count % 10) == 0) {
		rtouch_process();
		if ((g_ul_tick_count % 50) == 0) {
			lcd_timer_tick();
		}
	}
}

// touch panel event handler
static void event_handler(rtouch_event_t const *event)
{
	switch(event->type) {
		case RTOUCH_MOVE:
		view_mouse_move(event->panel.x, event->panel.y);
		break;
		case RTOUCH_PRESS:
		view_mouse_down(event->panel.x, event->panel.y);
		break;
		case RTOUCH_RELEASE:
		view_mouse_up(event->panel.x, event->panel.y);
		break;
		default:
		break;
	}
}

// values for calibration status
#define CALIB_INIT 0
#define CALIB_P1 1
#define CALIB_P2 2
#define CALIB_P3 3
#define CALIB_P4 4
#define CALIB_P5 5
#define CALIB_DONE 6

#define PASSPHRASE_BUFSIZE 101
#define PIN_BUFSIZE 101

// file name for encrypted key file
static char KEY_FILE_NAME[] = "0:keys.gpg";

// state variables
static volatile FATFS fs;
static volatile FIL file_object;
static volatile int file_format_valid = 1;
static volatile char *items = NULL;
static volatile char pin[PIN_BUFSIZE];
static volatile int sd_card_inserted;
static volatile	int pin_ok = 0;
static volatile	int pin_entered = 0;
static volatile int pin_attempts = 0;
static volatile int decrypt_attempted = 0;
static volatile int decrypt_ok = 0;

#define N_CALIB_POINTS 5

// persistent state variables
static volatile struct {
	rtouch_calibration_point_t gs_calibration_points[N_CALIB_POINTS];
	int calib_state;
	char passphrase[PASSPHRASE_BUFSIZE];
	char pin[PIN_BUFSIZE];
	int pin_set;
	int passphrase_set;
	uint8_t digest[SHA1_DIGEST_SIZE]; // hash to know if state is valid
} g_state;

// compute the persistent state digest
static void compute_state_digest(uint8_t digest[SHA1_DIGEST_SIZE]) {
	uint8_t *p1;
	uint8_t *p2;
	sha1_ctx ctx;
	
	p1 = (uint8_t *)&g_state;
	p2 = g_state.digest;
	sha1_hash(&ctx, p1, p2 - p1);
	sha1_digest(&ctx, digest);
}

// set the state digest to mark it as valid
static void set_state_digest(void) {
	compute_state_digest(g_state.digest);
}

// verify that the persistent state is valid by checking the digest
static int verify_state_digest(void) {
	uint8_t digest[SHA1_DIGEST_SIZE];
	
	compute_state_digest(digest);
	return (memcmp(digest, g_state.digest, SHA1_DIGEST_SIZE) == 0);
}

// initialize the state
static void init_state(void) {
	int i;

	g_state.calib_state = CALIB_INIT;
	for (i = 0; i < PASSPHRASE_BUFSIZE; i++) g_state.passphrase[i] = 0;
	for (i = 0; i < PIN_BUFSIZE; i++) g_state.pin[i] = 0;
	g_state.pin_set = 0;
	g_state.passphrase_set = 0;
	g_state.gs_calibration_points[0].panel.x = CALIB_POINTS_X1;
	g_state.gs_calibration_points[0].panel.y = CALIB_POINTS_Y1;
	
	g_state.gs_calibration_points[1].panel.x = CALIB_POINTS_X2;
	g_state.gs_calibration_points[1].panel.y = CALIB_POINTS_Y1;
	
	g_state.gs_calibration_points[2].panel.x = CALIB_POINTS_X2;
	g_state.gs_calibration_points[2].panel.y = CALIB_POINTS_Y2;
	
	g_state.gs_calibration_points[3].panel.x = CALIB_POINTS_X1;
	g_state.gs_calibration_points[3].panel.y = CALIB_POINTS_Y2;
	
	g_state.gs_calibration_points[4].panel.x = CALIB_POINTS_X0;
	g_state.gs_calibration_points[4].panel.y = CALIB_POINTS_Y0;
	 
}

// NVRAM address for persistent state
#define STATE_ADDRESS_INT (IFLASH_ADDR + IFLASH_SIZE- IFLASH_PAGE_SIZE*8)

// read the persistent state from NVRAM
static void read_state(void) {
	nvm_read(INT_FLASH, STATE_ADDRESS_INT, &g_state, sizeof(g_state));
	if (!verify_state_digest()) {
		// no valid state read - initialize to default
		init_state();
	}
	if (g_state.calib_state == CALIB_DONE) {
		rtouch_compute_calibration((rtouch_calibration_point_t *) &g_state.gs_calibration_points);
	}
}

// write the persistent state to NVRAM
static void write_state(void) {
	set_state_digest();
	nvm_write(INT_FLASH, STATE_ADDRESS_INT, &g_state, sizeof(g_state));
}

// check if SD card is valid
static int sd_valid(void) {
	Ctrl_status status;
	FRESULT res;
	
	do {
		status = sd_mmc_test_unit_ready(0);
	} while (status == CTRL_BUSY);
	if (status != CTRL_GOOD) return 0;
	
	memset(&fs, 0, sizeof(FATFS));
	// attempt to mount unit
	res = f_mount(LUN_ID_SD_MMC_0_MEM, &fs);
	
	return (res == FR_OK);
}

// check if key file exists
static int file_exists(void) {
	FRESULT res;
	
	res = f_stat(KEY_FILE_NAME, NULL);
	return (res == FR_OK);
}

// attempt to decrypt key file
static int decrypt_file(void) {
	mpgp_stream_t *in;
	mpgp_stream_t *key_stream;
	size_t buf_len = 1024;
	size_t bytes_read;
	char *buf;
	FRESULT res;
	
	// open file
	res = f_open(&file_object, KEY_FILE_NAME, FA_OPEN_EXISTING | FA_READ);
	if (res != FR_OK) return 0;
	// wrap FatFS file handle in stream interface
	in = mpgp_ff_sopen(&file_object);
	if (in == NULL) return 0;
	// decrypt file
	key_stream = mpgp_open(in, g_state.passphrase, strlen(g_state.passphrase));
	if (key_stream == NULL) {
		return 0;		
	}
	// free memory for key items if already allocated
	if (items != NULL) {
		free(items);
	}
	
	buf = malloc(buf_len);
	if (buf == NULL) return 0;
	bytes_read = mpgp_sread(key_stream, buf, 1, buf_len);
	buf[bytes_read] = 0;
	items = buf;
	mpgp_sclose(key_stream);
	
	return 1;
}

// check if used supplied PIN is correct
static int verify_pin(void) {
	return (strcmp(g_state.pin, pin) == 0);
}

// messages to user
static char const *MSG_INSERT_SD = "Insert SD card";
static char const *MSG_SD_INVALID = "SD card cannot be read";
static char const *MSG_NO_FILE = "Key file not found";
static char const *MSG_FILE_BAD_FORMAT = "Unknown key file format";
static char const *MSG_ENTER_PASSPHRASE = "Enter passphrase to unlock";
static char const *MSG_WRONG_PASSPHRASE = "Wrong passphrase - try again";
static char const *MSG_ASSIGN_PIN = "Assign PIN";
static char const *MSG_ENTER_PIN = "Enter PIN";
static char const *MSG_WRONG_PIN_1 = "Wrong PIN - 2 attempts left";
static char const *MSG_WRONG_PIN_2 = "Wrong PIN - 1 attempt left";

// determine which view to display based on state
static void set_next_view(void) {
	if (g_state.calib_state != CALIB_DONE) {
		// calibration needed
		g_state.calib_state = CALIB_INIT;
		lcd_set_view(VIEW_CALIB);
		lcd_start_command(CMD_CALIB_LBL_FADE_IN);
		return;
	}
	if (!sd_card_inserted) {
		// no SD card inserted
		// display title screen to alert user
		decrypt_attempted = 0;
		decrypt_ok = 0;
		pin_ok = 0;
		pin_entered = 0;
		file_format_valid = 1;
		lcd_set_title_msg(MSG_INSERT_SD);
		lcd_set_view(VIEW_TITLE);
		lcd_start_command(CMD_FADE_IN);
		return;
	}
	if (!sd_valid()) {
		// SD card not valid - inform user
		lcd_set_title_msg(MSG_SD_INVALID);
		lcd_set_view(VIEW_TITLE);
		lcd_start_command(CMD_FADE_IN);
		return;
	}
	if (!file_exists()) {
		// key file does not exist - inform user
		lcd_set_title_msg(MSG_NO_FILE);
		lcd_set_view(VIEW_TITLE);
		lcd_start_command(CMD_FADE_IN);
		return;
	}
	// attempt decryption
	if ((!decrypt_attempted) && g_state.passphrase_set) {
		// attempt to decrypt file
		decrypt_ok = decrypt_file();
	}
	decrypt_attempted = 1;
	if (!decrypt_ok) {
		// decryption failed - prompt for passphrase
		lcd_set_passphrase_buffer(g_state.passphrase, PASSPHRASE_BUFSIZE);
		g_state.passphrase_set = 0;
		decrypt_attempted = 0;
		g_state.pin_set = 0;
		lcd_set_passphrase_msg(MSG_ENTER_PASSPHRASE);
		lcd_set_view(VIEW_PASS);
		lcd_start_command(CMD_FADE_IN);
		return;
	}
	/*if (!file_valid) {
		lcd_set_title_msg(MSG_FILE_INVALID);
		lcd_set_view(VIEW_TITLE);
		lcd_start_command(CMD_FADE_IN);
		return;
	}*/
	if (!file_format_valid) {
		// file format is not valid - inform user
		lcd_set_title_msg(MSG_FILE_BAD_FORMAT);
		lcd_set_view(VIEW_TITLE);
		lcd_start_command(CMD_FADE_IN);
		return;
	}
	// attempt to set keys
	if (!lcd_set_keys(items)) {
		// could not set keys - mark file format as invalid
		file_format_valid = 0;
		set_next_view();
		return;
	}
	// verify pin
	if (pin_entered && g_state.pin_set) {
		pin_ok = verify_pin();
	}
	if (!g_state.pin_set) {
		// no PIN set - promt user for new PIN
		lcd_set_pin_msg(MSG_ASSIGN_PIN);
		lcd_set_pin_buffer(g_state.pin, PIN_BUFSIZE);
		pin_entered = 0;
		pin_ok = 0;
		lcd_set_view(VIEW_PIN);
		lcd_start_command(CMD_FADE_IN);
		return;
	}
	if (!pin_entered || !pin_ok) {
		// promt for PIN
		lcd_set_pin_msg(MSG_ENTER_PIN);
		lcd_set_pin_buffer(pin, PIN_BUFSIZE);
		pin_entered = 0;
		pin_attempts = 3;
		lcd_set_view(VIEW_PIN);
		lcd_start_command(CMD_FADE_IN);
		return;
	}
	
	file_format_valid = 1;
	lcd_set_view(VIEW_KEY);
	lcd_start_command(CMD_FADE_IN);
}


#define CALIB_OVERSAMPLING 100

// get calibration data from user
static void get_calib_point(int i) {
	uint32_t x[CALIB_OVERSAMPLING],y[CALIB_OVERSAMPLING];
	int j;
	
	// wait for new touch panel press
	while (rtouch_is_pressed()) wdt_restart(WDT);
	while (!rtouch_is_pressed()) wdt_restart(WDT);
	
	// collect touch panel samples
	for (j = 0; j < CALIB_OVERSAMPLING; j++) {
		if (!rtouch_is_pressed()) return;
		rtouch_get_raw_point(&x[j], &y[j]);
	}
	// sort samples to obtain median
	quicksort(x, CALIB_OVERSAMPLING);
	quicksort(y, CALIB_OVERSAMPLING);
	g_state.gs_calibration_points[i].raw.x = x[CALIB_OVERSAMPLING/2];
	g_state.gs_calibration_points[i].raw.y = y[CALIB_OVERSAMPLING/2];
	
	// fade out current calibration point
	switch (i) {
	case 0:
		g_state.calib_state = CALIB_INIT;
		lcd_start_command(CMD_CALIB_POINT_1_FADE_OUT);
		break;
	case 1:
		g_state.calib_state = CALIB_INIT;
		lcd_start_command(CMD_CALIB_POINT_2_FADE_OUT);
		break;
	case 2:
		g_state.calib_state = CALIB_INIT;
		lcd_start_command(CMD_CALIB_POINT_3_FADE_OUT);
		break;
	case 3:
		g_state.calib_state = CALIB_INIT;
		lcd_start_command(CMD_CALIB_POINT_4_FADE_OUT);
		break;
	case 4:
		g_state.calib_state = CALIB_INIT;
		lcd_start_command(CMD_CALIB_POINT_5_FADE_OUT);
		break;		
	}
	rtouch_wait_released();
}

// callback from UI that command is complete
void lcd_command_complete(int command);
void lcd_command_complete(int command) {

	switch (command) {
		case CMD_CALIB_LBL_FADE_IN:
		lcd_start_command(CMD_CALIB_POINT_1_FADE_IN);
		break;
		case CMD_CALIB_LBL_FADE_OUT:
		// calibration done
		set_next_view();
		break;
		case CMD_CALIB_POINT_1_FADE_IN:
		g_state.calib_state = CALIB_P1;
		break;
		case CMD_CALIB_POINT_1_FADE_OUT:
		lcd_start_command(CMD_CALIB_POINT_2_FADE_IN);
		break;
		case CMD_CALIB_POINT_2_FADE_IN:
		g_state.calib_state = CALIB_P2;
		break;
		case CMD_CALIB_POINT_2_FADE_OUT:
		lcd_start_command(CMD_CALIB_POINT_3_FADE_IN);
		break;
		case CMD_CALIB_POINT_3_FADE_IN:
		g_state.calib_state = CALIB_P3;
		break;
		case CMD_CALIB_POINT_3_FADE_OUT:
		lcd_start_command(CMD_CALIB_POINT_4_FADE_IN);
		break;
		case CMD_CALIB_POINT_4_FADE_IN:
		g_state.calib_state = CALIB_P4;
		break;
		case CMD_CALIB_POINT_4_FADE_OUT:
		lcd_start_command(CMD_CALIB_POINT_5_FADE_IN);
		break;
		case CMD_CALIB_POINT_5_FADE_IN:
		g_state.calib_state = CALIB_P5;
		break;
		case CMD_CALIB_POINT_5_FADE_OUT:
		// check if calibration quality is satisfactory
		if (rtouch_compute_calibration((rtouch_calibration_point_t *) &g_state.gs_calibration_points) == 0) {
			g_state.calib_state = CALIB_DONE;
			write_state();
			lcd_start_command(CMD_CALIB_LBL_FADE_OUT);
		}
		else {
			lcd_start_command(CMD_CALIB_POINT_1_FADE_IN);
		}
		break;
		case CMD_FADE_IN:
		if (lcd_get_view() == VIEW_LOGO) {
			lcd_start_command(CMD_FADE_OUT);
		}
		break;
		case CMD_FADE_OUT:
		set_next_view();
		break;
	}

}

// callback from UI that passphrase OK button was clicked
void lcd_passphrase_ok(void);
void lcd_passphrase_ok(void) {
	g_state.passphrase_set = 1;
	decrypt_ok = decrypt_file();
	decrypt_attempted = 1;
	if (decrypt_ok) {
		lcd_start_command(CMD_FADE_OUT);
	}
	else {
		lcd_set_passphrase_msg(MSG_WRONG_PASSPHRASE);
	}
}

// callback from UI that PIN OK button was clicked
void lcd_pin_ok(void);
void lcd_pin_ok(void) {
	if (!g_state.pin_set) {
		// requested to set PIN - write new PIN to NVRAM
		pin_entered = 1;
		g_state.pin_set = 1;
		strcpy(pin, g_state.pin);
		write_state();
		lcd_start_command(CMD_FADE_OUT);
		return;
	}
	if (strcmp(pin, g_state.pin) == 0) {
		// correct PIN entered
		pin_entered = 1;
		lcd_start_command(CMD_FADE_OUT);
	}
	else {
		// wrong PIN
		pin_attempts--;
		switch (pin_attempts) {
			case 2:
			lcd_set_pin_msg(MSG_WRONG_PIN_1);
			break;
			case 1:
			lcd_set_pin_msg(MSG_WRONG_PIN_2);
			break;
			default:
			g_state.passphrase_set = 0;
			decrypt_attempted = 0;
			decrypt_ok = 0;
			pin_ok = 0;
			pin_entered = 0;
			g_state.pin_set = 0;
			write_state();
			lcd_start_command(CMD_FADE_OUT);
			break;
		}
	}
}

static bool my_flag_autorize_keyboard_events = false;
bool my_callback_keyboard_enable(void)
{
	my_flag_autorize_keyboard_events = true;
	return true;
}
void my_callback_keyboard_disable(void)
{
	my_flag_autorize_keyboard_events = false;
}

#define KEY_DELAY 5

// callback from UI that key item was long pressed
void lcd_item_long_press(char *s);
void lcd_item_long_press(char *s) {
	
	send_keys(s);
}

void usb_init(void);
void usb_init(void)
{
	udc_start();
}

int main (void)
{
	sd_mmc_err_t last_mmc_err;
	sd_mmc_err_t new_mmc_err;
	
	KEY_FILE_NAME[0] = LUN_ID_SD_MMC_0_MEM + '0';
	
	// initialization
	sysclk_init();
	irq_initialize_vectors();
	cpu_irq_enable();
	board_init();
	//sleepmgr_init(); // Optional
	sd_mmc_init();
	nvm_init(INT_FLASH);
	udc_start();
	lcd_init();
	
	SysTick_Config(sysclk_get_cpu_hz() / 1000);	
	
	// initialize touch panel driver
	rtouch_init(LCD_WIDTH, LCD_HEIGHT);
	rtouch_enable();
	rtouch_set_event_handler(event_handler);
	
	// read persistent state
	read_state();
	
	// initialize SD inserted state
	last_mmc_err = sd_mmc_check(0);
	sd_card_inserted = (last_mmc_err != CTRL_NO_PRESENT);
	
	lcd_set_view(VIEW_LOGO);
	lcd_start_command(CMD_FADE_IN);
	
	while (1) {

		// cycle through calibration points
		while (g_state.calib_state != CALIB_DONE) {
			switch (g_state.calib_state) {
			case CALIB_P1:
				get_calib_point(0);
				break;
			case CALIB_P2:
				get_calib_point(1);
				break;
			case CALIB_P3:
				get_calib_point(2);
				break;
			case CALIB_P4:
				get_calib_point(3);
				break;
			case CALIB_P5:
				get_calib_point(4);
				break;
			default:
				break;
			}
		}
		
		// check if SD card is inserted
		new_mmc_err = sd_mmc_check(0);
		// a change in SD inserted state triggers a fade out
		// and switch to appropriate view
		if (new_mmc_err != last_mmc_err) {
			sd_card_inserted = (new_mmc_err != CTRL_NO_PRESENT);
			last_mmc_err = new_mmc_err;
			lcd_start_command(CMD_FADE_OUT);
		}
		
		wdt_restart(WDT);
	}
}

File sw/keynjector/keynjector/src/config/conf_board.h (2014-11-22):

/**
 * \file
 *
 * \brief User board configuration template
 *
 */

#ifndef CONF_BOARD_H
#define CONF_BOARD_H

#define ACCESS_MEM_TO_RAM_ENABLED

/** Board oscillator settings */
#define BOARD_FREQ_SLCK_XTAL        (32768U)
#define BOARD_FREQ_SLCK_BYPASS      (32768U)
#define BOARD_FREQ_MAINCK_XTAL      (12000000U)
#define BOARD_FREQ_MAINCK_BYPASS    (12000000U)

/** board main clock xtal startup time */
#define BOARD_OSC_STARTUP_US   15625

#define TP_RESET    PIO_PA8_IDX
#define TP_READ		PIO_PA9_IDX
#define TP_WRITE	PIO_PA10_IDX
#define TP_DC		PIO_PA11_IDX
#define TP_CS		PIO_PA25_IDX
#define TP_DATA_PORT	IOPORT_PIOA
#define TP_DATA_MASK	0x000000FF

/** HSMCI pins definition. */
/*! Number of slot connected on HSMCI interface */
#define SD_MMC_HSMCI_MEM_CNT      1
#define SD_MMC_HSMCI_SLOT_0_SIZE  4
#define PINS_HSMCI   {0x3fUL << 26, PIOA, ID_PIOA, PIO_PERIPH_C, PIO_PULLUP}
/** HSMCI MCCDA pin definition. */
#define PIN_HSMCI_MCCDA_GPIO            (PIO_PA28_IDX)
#define PIN_HSMCI_MCCDA_FLAGS           (PIO_PERIPH_C | PIO_DEFAULT)
/** HSMCI MCCK pin definition. */
#define PIN_HSMCI_MCCK_GPIO             (PIO_PA29_IDX)
#define PIN_HSMCI_MCCK_FLAGS            (PIO_PERIPH_C | PIO_DEFAULT)
/** HSMCI MCDA0 pin definition. */
#define PIN_HSMCI_MCDA0_GPIO            (PIO_PA30_IDX)
#define PIN_HSMCI_MCDA0_FLAGS           (PIO_PERIPH_C | PIO_PULLUP)
/** HSMCI MCDA1 pin definition. */
#define PIN_HSMCI_MCDA1_GPIO            (PIO_PA31_IDX)
#define PIN_HSMCI_MCDA1_FLAGS           (PIO_PERIPH_C | PIO_PULLUP)
/** HSMCI MCDA2 pin definition. */
#define PIN_HSMCI_MCDA2_GPIO            (PIO_PA26_IDX)
#define PIN_HSMCI_MCDA2_FLAGS           (PIO_PERIPH_C | PIO_PULLUP)
/** HSMCI MCDA3 pin definition. */
#define PIN_HSMCI_MCDA3_GPIO            (PIO_PA27_IDX)
#define PIN_HSMCI_MCDA3_FLAGS           (PIO_PERIPH_C | PIO_PULLUP)
/** SD/MMC card detect pin definition. */

#define PIN_HSMCI_CD {PIO_PA16, PIOA, ID_PIOA, PIO_INPUT, PIO_PULLUP, PIO_DEBOUNCE}
#define SD_MMC_0_CD_GPIO            (PIO_PA16_IDX)
#define SD_MMC_0_CD_PIO_ID          ID_PIOA
#define SD_MMC_0_CD_FLAGS           (PIO_INPUT | PIO_PULLUP)
#define SD_MMC_0_CD_DETECT_VALUE    0

#define CONF_BOARD_SD_MMC_HSMCI

/** Touchscreen controller IRQ & Busy pin definition. */
#define BOARD_ADS7843_IRQ_GPIO      PIO_PA24_IDX
#define BOARD_ADS7843_IRQ_FLAGS     PIO_INPUT | PIO_PULLUP
#define BOARD_ADS7843_IRQ_WUP_ID    (1 << 15)
#define BOARD_ADS7843_BUSY_GPIO     PIO_PA15_IDX
#define BOARD_ADS7843_BUSY_FLAGS    PIO_INPUT | PIO_PULLUP

#define CONF_BOARD_ADS7843

/** Base address of SPI peripheral connected to the touchscreen controller. */
#define BOARD_ADS7843_SPI_BASE      SPI
/** Identifier of SPI peripheral connected to the touchscreen controller. */
#define BOARD_ADS7843_SPI_ID        ID_SPI
/** Chip select connected to the touchscreen controller. */
#define BOARD_ADS7843_SPI_NPCS      2

/** SPI MISO pin definition. */
#define SPI_MISO_GPIO             (PIO_PA12_IDX)
#define SPI_MISO_FLAGS       (PIO_PERIPH_A | PIO_DEFAULT)
/** SPI MOSI pin definition. */
#define SPI_MOSI_GPIO             (PIO_PA13_IDX)
#define SPI_MOSI_FLAGS       (PIO_PERIPH_A | PIO_DEFAULT)
/** SPI SPCK pin definition. */
#define SPI_SPCK_GPIO             (PIO_PA14_IDX)
#define SPI_SPCK_FLAGS       (PIO_PERIPH_A | PIO_DEFAULT)

#define SPI_NPCS2_PB2_GPIO        (PIO_PB2_IDX)
#define SPI_NPCS2_PB2_FLAGS       (PIO_PERIPH_B | PIO_DEFAULT)

#endif // CONF_BOARD_H

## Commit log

2014-11-22 added initial version of case
    [keynjector-case.scad]
2014-11-23 added keynjector KiCad project
    [keynjector.kicad_pcb, keynjector.sch, keynjector_debug.sch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]
2014-11-25 added bill of materials
    [BOM.ods]
2014-11-25 added zifbrkout KiCad project
    [zifbrkout.kicad_pcb, zifbrkout.sch]
2014-11-25 adjusted ignore for KiCad backup files
2014-11-26 * removed logo from key screen * added up/down buttons to scroll key screen
2014-11-29 improved case with holes for screws and nuts
    [keynjector-case.scad]
2014-12-02 added license text to KiCad sheets
    [keynjector.sch, keynjector_debug.sch, keynjector_lcd_touch.sch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]
2014-12-02 moved debug header to board back to facilitate debug with board in case
    [keynjector.kicad_pcb]
2014-12-03 moved erase testpoint to back to facilitate debugging/reprogramming in debug case adjusted version number on PCB to 1.0.0 for first real release
    [keynjector.kicad_pcb]
2014-12-04 added comments adjusted code to serve as library
    [keynjector-case.scad]
2014-12-04 added screen support
    [keynjector-case.scad]
2014-12-04 changed edge cuts to accomodate for screen support
    [keynjector.kicad_pcb]
2014-12-05 added copyright notices added COPYING file with GPL v2 license added README file moved font files
    [BOM.ods, zifbrkout.kicad_pcb, zifbrkout.sch]
2014-12-05 added OpenSCAD files to generate parts suitable for 3D printing added a simple .bat build file for case parts
    [keynjector-case-back-dbg-normalized.scad, keynjector-case-back-normalized.scad, keynjector-case-front-normalized.scad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]
2015-02-04 revised debug case due to collision of debug connector with case in test print
    [keynjector-case.scad, keynjector-holder-and-btn-dbg-normalized.scad]
2015-03-24 changed keynjector case after feedback from 3D printing
    [keynjector-case.scad, keynjector-holder-and-btn-dbg-normalized.scad]

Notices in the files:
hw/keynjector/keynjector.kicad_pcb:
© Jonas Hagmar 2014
